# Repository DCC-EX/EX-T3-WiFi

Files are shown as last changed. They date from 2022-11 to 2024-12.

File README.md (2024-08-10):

<h1>EX-T3-WiFi <small>(T3 = Tactile Touch Throttle)</small></h1>

## WiFi throttle for DCC-EX Command Stations

#### The CS will need to be WiFi compatible and version 4.1.3+

#
### ⚠ Please note before deciding to buy parts this has been a solo project and may have unknown bugs and require some tinkering, please report any issues on GitHub ⚠

### 🛈 To upload the code you'll need a Chromium based web browser (Chrome, Opera, Edge) or Visual Studio Code and PlatformIO 🛈

#

## Parts
 - DFRobot FireBeetle 2 - DFR0654-F - https://www.dfrobot.com/product-2231.html (If you prefer a more permanent setup you could use the FireBeetle2 that doesn't have headers pre-soldered)
 - DFRobot Fermion: 3.5” 480x320 TFT LCD Capacitive Touchscreen - DFR0669 - https://www.dfrobot.com/product-2107.html
 - DFRobot Fermion: EC11 Rotary Encoder - SEN0235 - https://www.dfrobot.com/product-1611.html
 - DFRobot Fermion: LIS2DW12 Triple Axis Accelerometer - SEN0405 - https://www.dfrobot.com/product-2337.html **(This is optional but will allow the throttle to rotate the display with orientation)**
 - Miniature Slide Switch SPDT - I used one from here https://www.hobbytronics.co.uk/slide-switch?search=switch
 to fit the case it'll need to be the same dimensions *(19mm long, 5.6mm wide, 5mm high and mounting holes 15mm apart)*
 - 3000mah\2000mah LiPo battery - https://shop.pimoroni.com/products/lipo-battery-pack?variant=20429082247 **⚠ This battery has the terminals the correct way but before connecting any battery check the wires are the right way round on the plug ⚠**
 - All screws are self tapping cap heads;
	- M2x5mm - x6 (+2 if using accelerometer) (+2 if using 3000mah battery)
	- M2x8mm - x6 (+2 if using 2000mah battery)
	- M3x6mm - x2
	- M3x20mm - x4
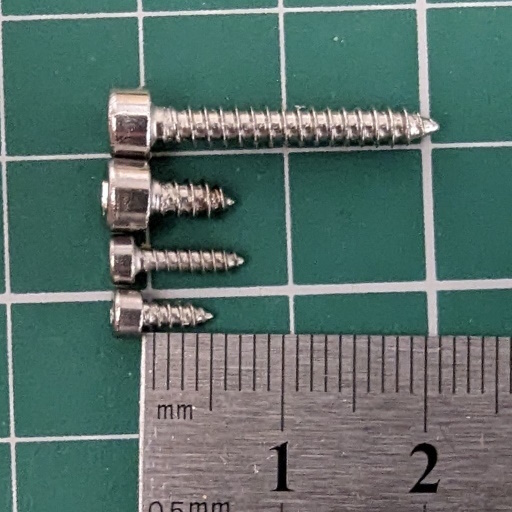
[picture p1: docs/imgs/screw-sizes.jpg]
	
 - Stranded and solid core wire depending on preference
 - If using headers then you'll need some right angle male, right angle female and standard female
 - Heatshrink for wires
 - MicroSD card (16GB is a good common size)

#
- [Assembly](/docs/assembly.md)
- [Web Browser Uploading](/docs/browser.md)
- [VSCode Uploading](/docs/code.md)
- [Throttle Setup](/docs/setup.md)
- [Managing Locos](/docs/locos.md)
- [Throttle Menu](/docs/menu.md)
- [Throttle Settings](/docs/settings.md)
- [Running Locos](/docs/running.md)
- [Decoder Programming](/docs/programming.md)

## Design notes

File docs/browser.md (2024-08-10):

# Web Browser Uploading

> ⚠ Web browser uploading only works with Chromium based web browsers such as Chrome, Opera & Edge ⚠

Download the lastest release from https://github.com/DCC-EX/EX-T3-WiFi/releases (`firmware.bin`) then go to https://espressif.github.io/esptool-js/

Plug in the throttle to your computer and click the `Connect` button (You'll be prompted to select the COM port the throttle is on).

If the throttle has been detected it should read **Connected to device**.

On the `Flash Address` field change the value to `0x0` then click the `Choose File` button and select the `firmware.bin` file you downloaded earlier.

You can now click the `Program` button to begin uploading.\
The upload progress will show below.\
Wait until it gets to 100% and finishes with the output of `Leaving...` before disconnecting the throttle.

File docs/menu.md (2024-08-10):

# Throttle Menu

## Loco
  * **By Address** - Display a keypad so a loco address can be selected.
  * **By Name** - Lists names of locos the throttle has configs for.
  * **By Group** - Lists the configured loco groups.
  * **Release** - Release the current loco.
  * **[Program](/docs/programming.md)** - Show the program track options.

## Accessories
 * **On** - Display a keypad so an accessory address can be selected and an **On** command sent.
 * **Off** - Display a keypad so an accessory address can be selected and an **Off** command sent.

## Power
 * **On/Off All** - Toggle power for **Main** and **Prog** tracks.
 * **On/Off Main** - Toggle power for the **Main** track.
 * **On/Off Prog** - Toggle power for the **Prog** track.
 * **Join Tracks** - Join the **Main** and **Prog** tracks.

## Settings
  * **T3 WiFi** - Starts the throttles local WiFi, Web Server and displays the throttle connection details.\
  *To manage the configs for locos you need to be on this screen.*
  * **Settings** - Manage the throttle settings.
  * **About** - Version details about the throttle and the CS if it's connected

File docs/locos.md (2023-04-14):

> Remember, to manage locos you'll need to start and connect to the web server on the throttle.\
Refer to [Throttle setup](/docs/setup.md).

# Managing Locos

Click the green **+** icon to add a new loco config or click the pencil icon on an existing loco to edit it.

<p align="center">
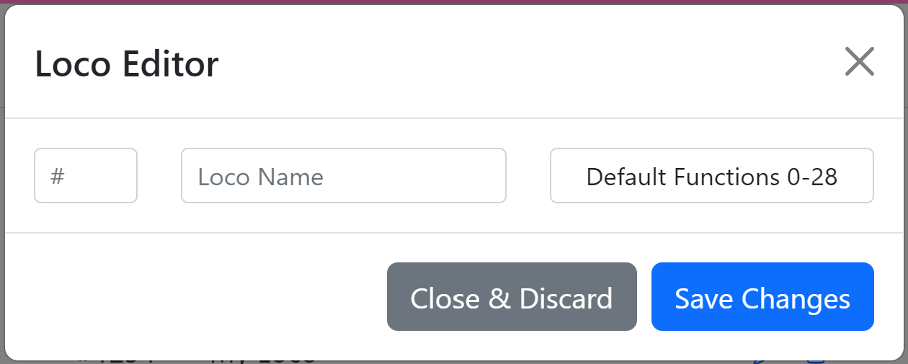
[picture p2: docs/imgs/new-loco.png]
  
</p>

A window will open where you can enter the details of the new loco.
* Enter the loco address in the field with the **#**.
* Enter a loco name in the **Loco Name** field, this is just for your reference so can be anything *(Max 20 characters)*.
* The last option is a dropdown, by default a loco will have buttons for functions 0-28 but you can create re-usable function sets or have a custom function set per loco.
<p align="center">
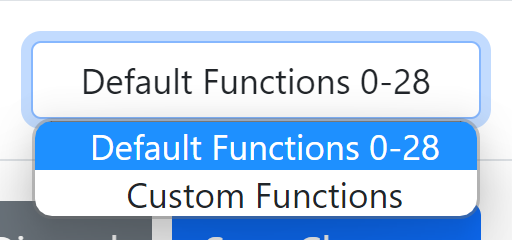
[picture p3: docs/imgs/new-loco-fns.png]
  
</p>

# Custom Functions

Each loco can have a custom function set.\
If you have more than 8 rows of buttons paging will be enabled and there will be 7 rows per page.\
Each row can have a max of 4 buttons.

<p align="center">
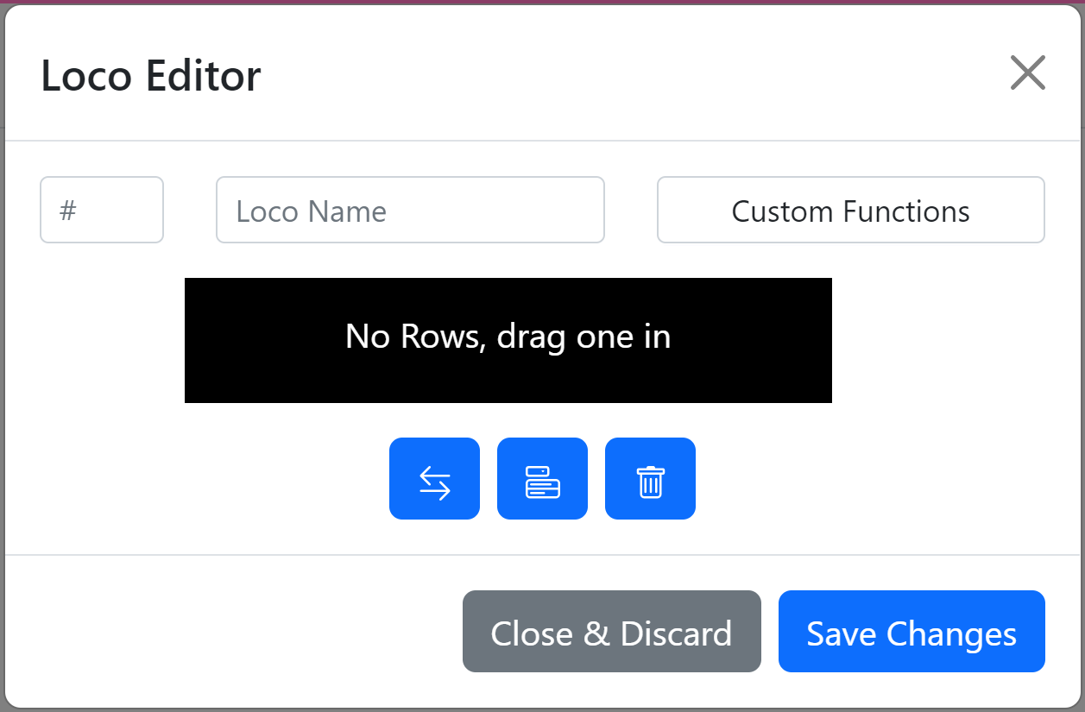
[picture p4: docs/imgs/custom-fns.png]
  
</p>

Start by dragging in a row, click and hold the button with the arrows then drag it into the black area.

<p align="center">
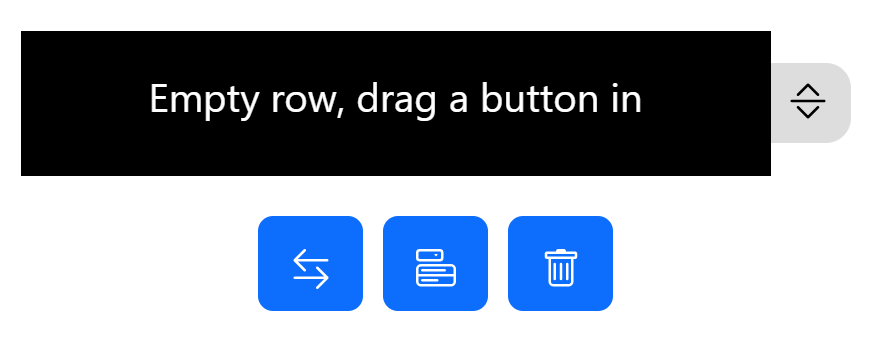
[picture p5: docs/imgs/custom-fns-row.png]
  
</p>

You can now drag in a button, click and hold the middle blue button and drag it on to the row.\
New buttons will use the next highest available fn #.

<p align="center">
  
</p>

Clicking the button will expand it so you can change the FN number and if it's a latching function or not.

<p align="center">
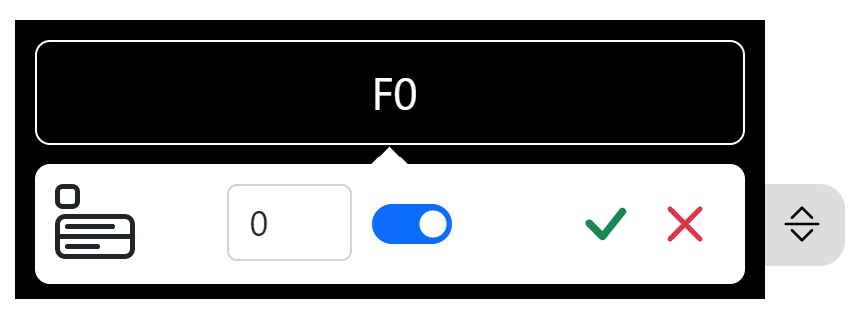
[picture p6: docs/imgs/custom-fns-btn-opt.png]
  
</p>

After making any changes remember to click the green tick icon so the changes are saved.\
If you've made changes you wan't to discard then click the red **X**.

For more advanced options click the icon to the left of the FN number.

From here you can set the button labels, colours and icons for **Idle** and **Pressed**.\
Clicking the icon circled in red will toggle between the **Idle** and **Pressed** states so you can preview.

> Click an icon to select it, click it again to deselect it.

<p align="center">
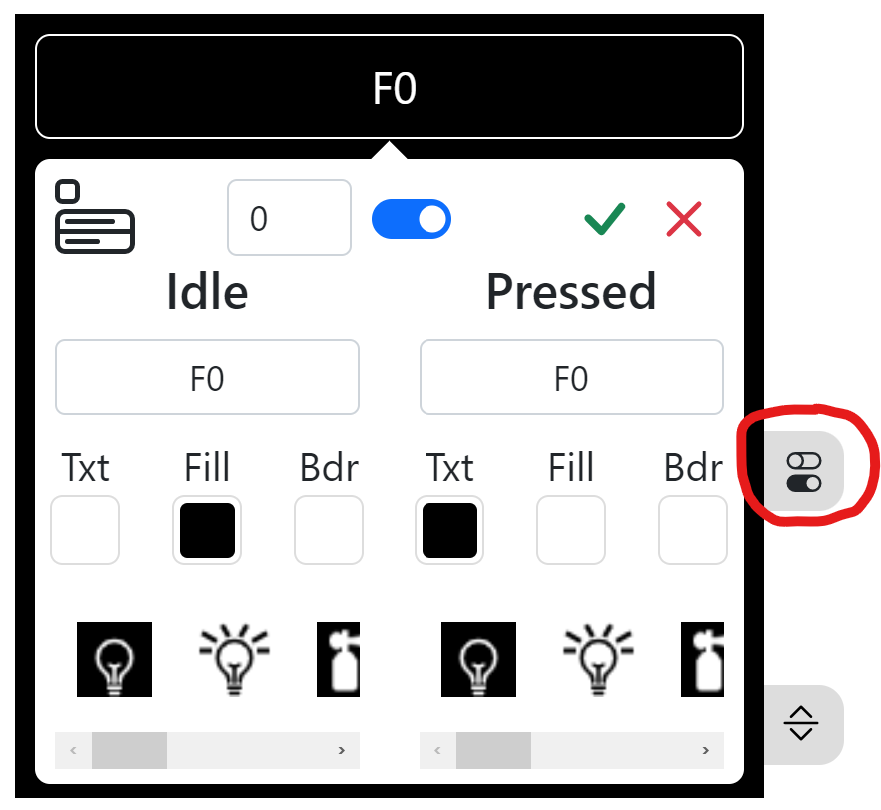
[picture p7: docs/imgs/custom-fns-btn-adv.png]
  
</p>

Rows can be dragged and reordered by clicking and holding the below icon that is at the end of each row.
<p align="center">
  
</p>
Buttons can be moved between rows by clicking and holding the dragging between rows.

> Remember a row can have a max of 4 buttons

# Function Sets

Reusable function sets can also be created.\
This is useful if you want to create a function set for a specific decoder that's used in multiple locos.

The function set name is for your reference.\
This will be the name that will appear in the dropdown when managing a loco as above.

Functions are created as per the instructions above.

<p align="center">
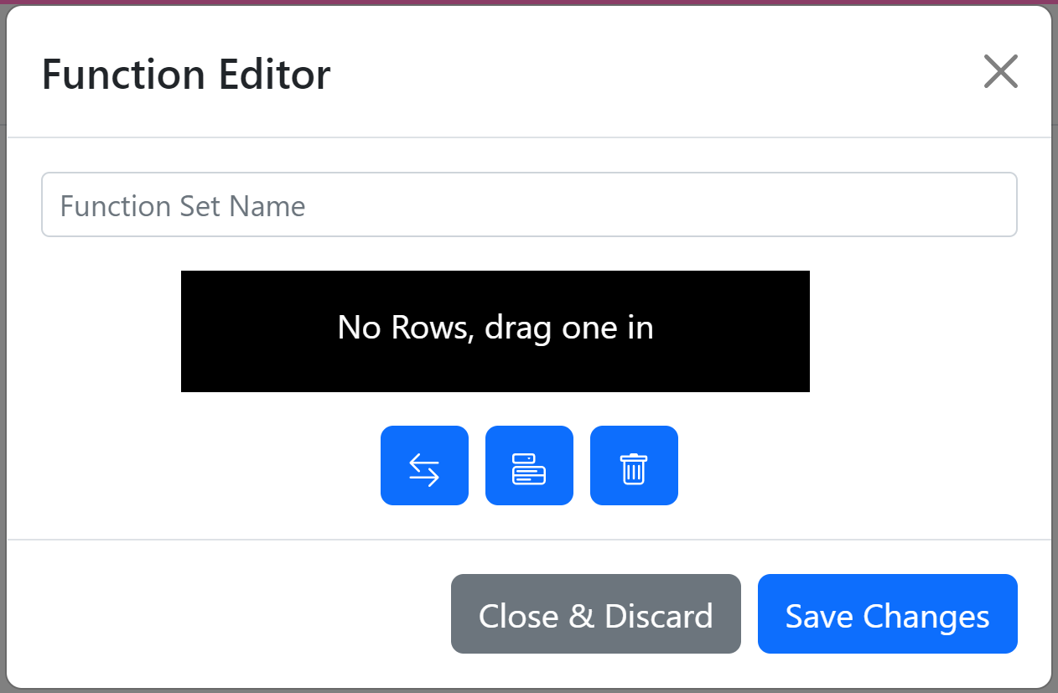
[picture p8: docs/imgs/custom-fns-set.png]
  
</p>

> There's also an upload icon (next to the +) so if a new decoder function set gets added to GitHub you can upload it without needing to take the SD card out.

# Groups

Here you can create loco groups that will show when the **By Group** button is pressed on the throttle menu.

Each group on the throttle will display as a button.\
Pressing a group button will then list the locos within it.\
You can then press a loco button to control that loco.

To add a new group click the large green **+** icon.\
This will add a new blank group.

<p align="center">
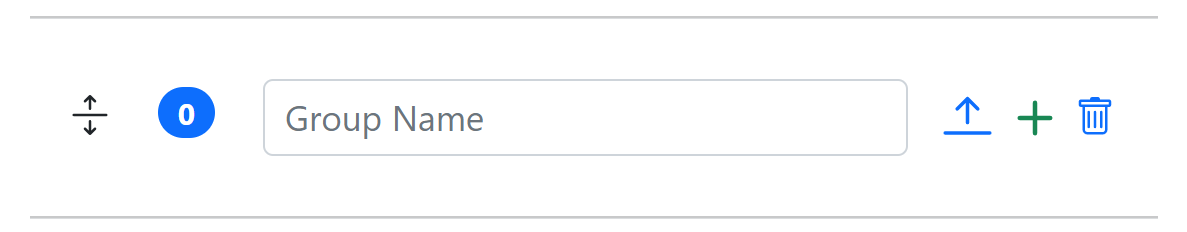
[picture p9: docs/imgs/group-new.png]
  
</p>

Enter a name in the `Group Name` field *(Max 20 characters)*.\
To add locos click the small green **+** icon on the group.\
This will open a new window where you can either enter loco addresses manually or select existing locos the throttle has a config for.

<p align="center">
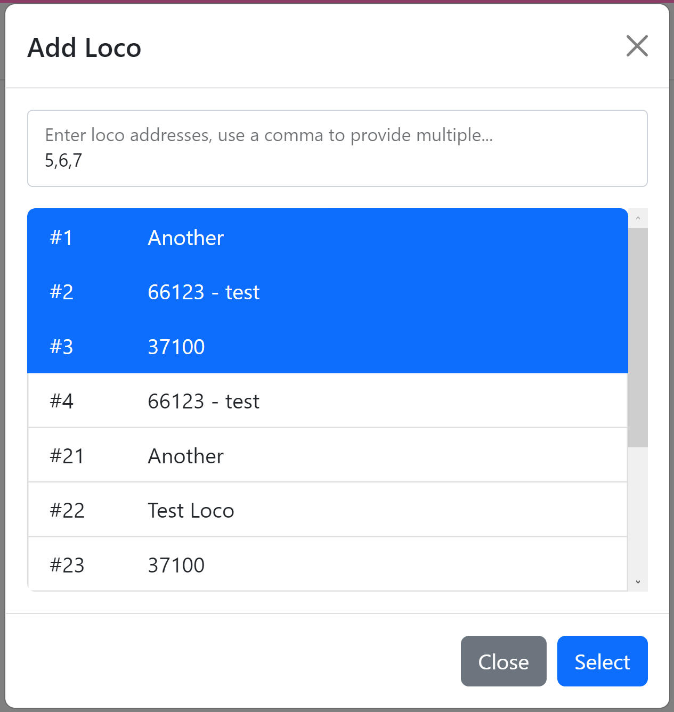
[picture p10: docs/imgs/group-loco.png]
  
</p>

Click the **Select** button to add the locos to the group.

<p align="center">
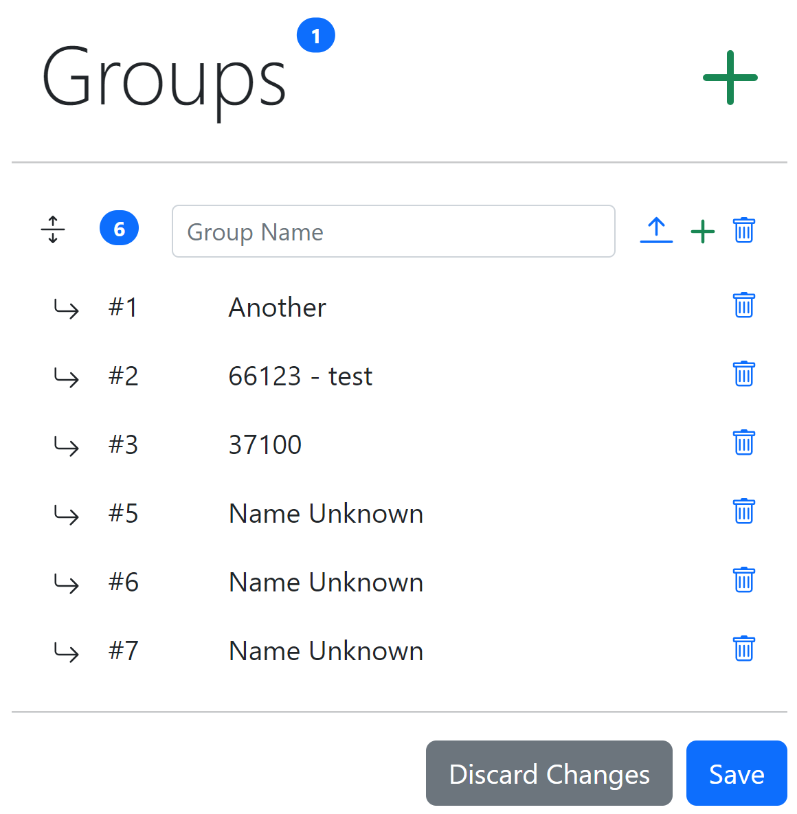
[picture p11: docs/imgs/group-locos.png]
  
</p>

Locos in the group will be listed below.\
If the throttle has a loco config it'll use the name otherwise it will show as **Name Unknown**.

Locos in the group will appear in the same order on the throttle.\
They can be reordered by click holding a dragging.\
Loco groups can also be reordered by dragging.

To save on display space a loco group is loaded as collapsed by default.\
You can expand/collapse a group to show the locos by clicking the arrow icons.

<p align="center">
  
  
</p>

# Icons

You can upload your own icons to use with the function buttons.

These need to be 24bit bitmaps with max dimensions of 30x30.

# Downloading/Uploading configs
Configs for locos, function sets and groups can be downloaded and uploaded.
An individual loco/function config can be downloaded by clicking the download icon to the left on the list.\
You can download all loco/function configs by clicking the download icon at the top of the list.\
Upload loco/function configs by clicking the upload icon at the top of the list, you can select single or multiple files to upload.\
(**Warning, Uploaded configs with the same addresses/names will overwrite any existing**).

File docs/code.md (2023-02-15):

# Uploading the Code

Start by uploading the embedded file system.\
On the PlatformIO tasks list click the `Upload Filesystem Image` task.
<p align="center">
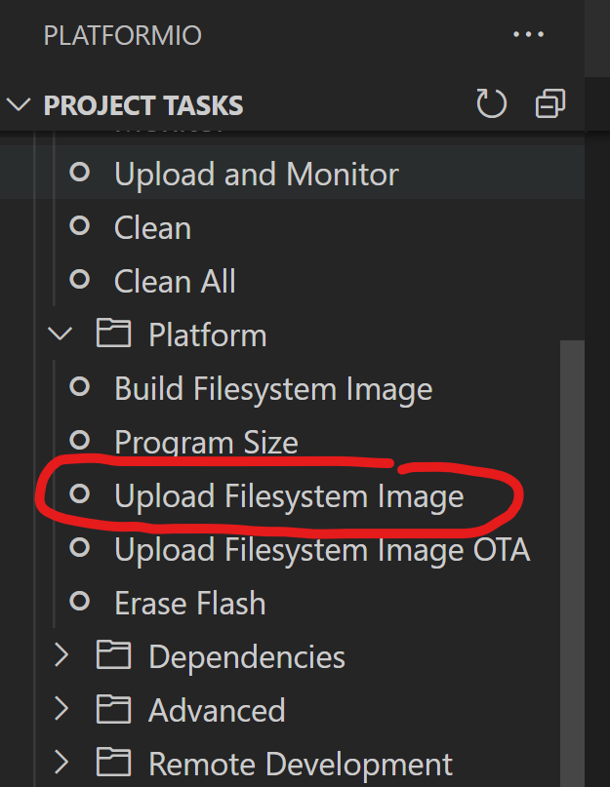
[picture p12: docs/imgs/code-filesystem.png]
  
</p>

## Uploading the code

Either of the options below will upload the code to the FireBeetle but **Upload and Monitor** can help with debugging any issues.
<p align="center">
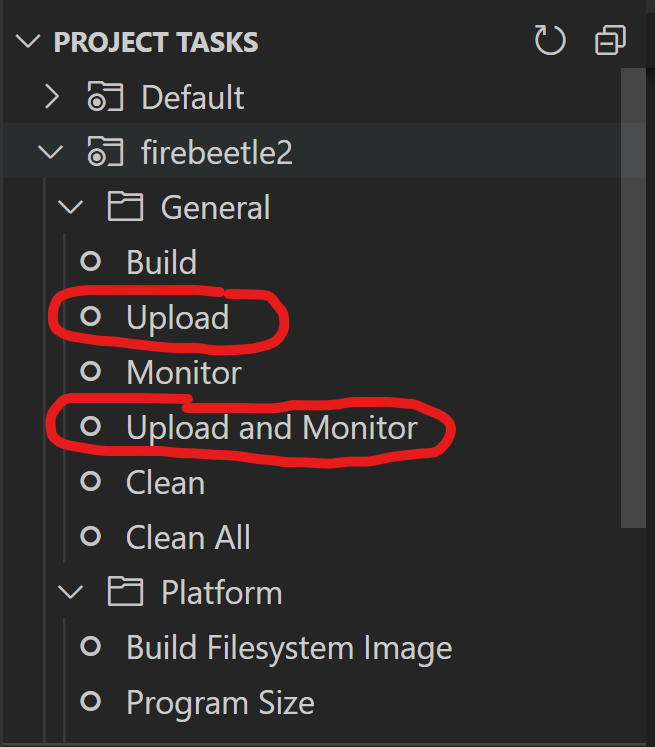
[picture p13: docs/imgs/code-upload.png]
  
</p>

# Command Station

If you want some extra functionality you'll need to update your **Command Station**.\
This step is optional and the throttle will still function without it but it won't be able to query the **CS** for the current power states.

Included is a file named `myFilter.cpp`, this needs to be copied to the folder that contains the **Command Station** code and uploaded to your **Command Station**.

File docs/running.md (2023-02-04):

# Running Locos

There's 3 ways to select a loco to control.

 * **By Address** - This will show a keypad where a loco address can be entered, press *Enter* to aquire and control the loco.
  * **By Name** - This will list all the locos the throttle has configs for, press a loco name to select.
  * **By Group** - This will list the groups *([as configured](locos.md#groups))*. Pressing a group button will list all the locos within that group, press a loco name to select.

---

The dial on the throttle is used to control the speed and direction.
* Turn clockwise to increase speed
* Turn counterclockwise to decrease speed
* Press once to change the loco direction

> Press and hold the dial to emergency stop all locos, the default is a 2 second hold but this can be changed in the throttle settings

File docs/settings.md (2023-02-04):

# Throttle Settings

These are under the **Settings** button from the menu.\
Settings are across multiple pages, you can scroll through them by using the paging buttons at the bottom.

## Loco UI

**Speed Step** - Can be 1, 2 or 4. This is the step value used to control loco speeds. *This is for the throttle only and not related to DCC speed steps*.

Some basic swipe gestures are supported on the throttle, Up, Down, Left & Right.\
Each gesture can trigger an action.

> Gestures only work while on the loco display

* **Keypad** - Show the keypad to select loco address.
* **Name** - Show the list of locos the throttle has configs for.
* **Group** - Show the loco groups the throttle has configs for.
* **Next** - If multiple locos have been selected then control the next.
* **Prev** - If multiple locos have been selected then control the previous.
* **Release** - Release the current loco.

> Locos are remembered in the order they were selected.\
So **Next** and **Prev** will follow this order.

**After swipe release**\
The action to perform if a swipe action is set to **release**.\
If this is set to **Next** or **Prev** and there's no locos the throttle will go back to the menu.

## Screen Rotation

* **Standard** - Screen above with rotary encoder below
* **Inverted** - Screen at below with rotary encoder above.
* **Accelerometer** - *Only if used*, display will rotate with pyhsical orientation.

## Pin Protect

This is just some basic security if you're concerned about guests being able to make changes to your settings.\
A 9 digit max pin can be set which will be required to access the `T3 WiFi` and `Settings` displays.

If the button is idle and reads `Not Set` no pin is set, you can set one by pressing the button which will show a keypad.\
Enter a pin and press `Enter` to set it or `Cancel` to go back to the settings.

To remove a pin press the button when it reads `Pin Set` to show the keypad then just press `Enter`. This will remove the pin and the button will change to `Not Set`.

> If you forget your pin it's stored in the `settings.json` file on the MicroSD card so can be read or reset.

## Emergency Stop Trigger Hold Duration

The milisecond count the encoder is pressed for to trigger an emergency stop of all locos (can be between 1000 - 5000 miliseconds).

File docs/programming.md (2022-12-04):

# Decoder Programming

Programming options are under the **Program** menu button and only work on the programming track.

- **Read Address** - Read the decoder address.
  1. If successful the decoder address will be displayed.
- **Write Address** - Write a new address to the decoder.
  1. Enter an address on the keypad (`1-10293`), press enter.
  2. A confirmation message will show, press **Yes** to write the address or **Cancel** to go back to the menu.
  2. If **Yes** was pressed then a success or fail result will show.
- **Read Byte** - Read a decoder CV value.
  1. Enter a CV number on the keypad (`1-1024`), press enter.
  2. If successful the byte value will be displayed.
- **Write Byte** - Write a CV value to the decoder.
  1. Enter a CV number on the keypad (`1-1024`), press enter.
  2. Enter a CV value on the keypad (`0-255`), press enter.
  3. A confirmation message will show, press **Yes** to write the CV value or **Cancel** to go back to the menu.
  4. If **Yes** was pressed then a success or fail result will show.
- **Read Bit** - Read a decoder CV value bit.
  1. Enter a CV number on the keypad (`1-1024`), press enter.
  2. Enter a bit number on the keypad (`0-7`), press enter.
  3. If successful the bit value will be displayed.
- **Write Bit** - Write a CV bit value.
  1. Enter a CV number on the keypad (`1-1024`), press enter.
  2. Enter a bit number on the keypad (`0-7`), press enter.
  3. Enter a bit value (`0-1`), press enter.
  4. A confirmation message will show, press **Yes** to write the CV bit value or **Cancel** to go back to the menu.
  5. If **Yes** was pressed then a success or fail result will show.

When on a keypad press **Cancel** to go back to the programming options menu.

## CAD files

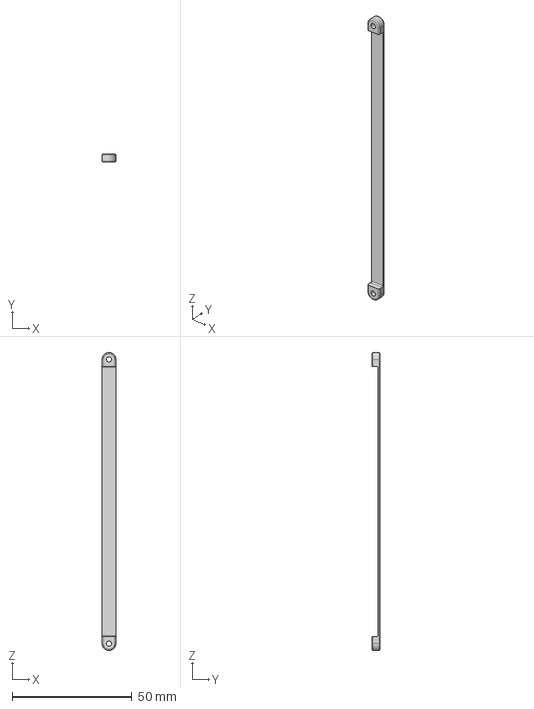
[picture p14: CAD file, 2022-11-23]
3d/Battery Strap - 2000mah.step
5.75 x 3.50 x 124.5 mm

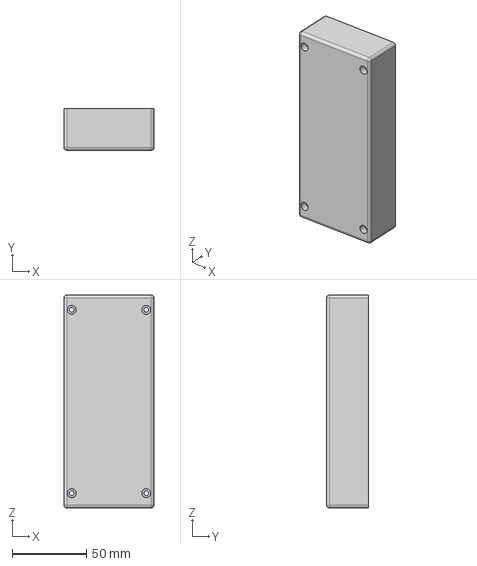
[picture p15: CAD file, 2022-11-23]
3d/Body.step
60.6 x 28.0 x 143.0 mm

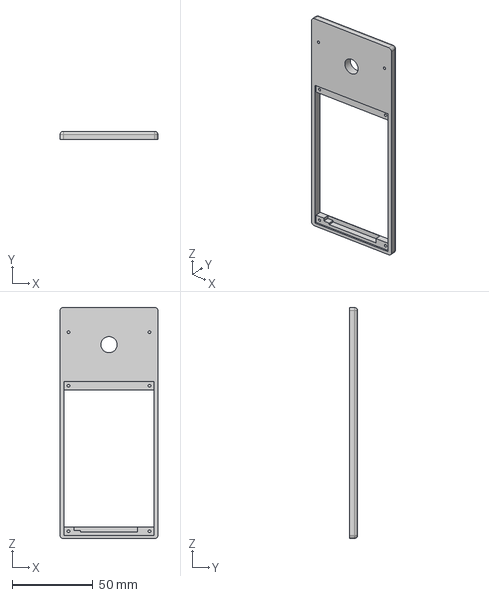
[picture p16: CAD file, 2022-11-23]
3d/Top.step
60.6 x 5.25 x 143.0 mm

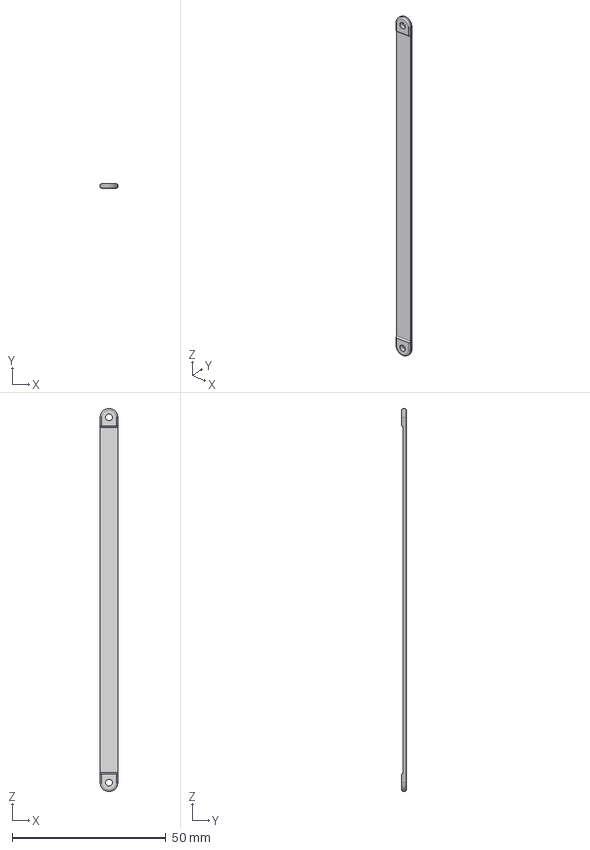
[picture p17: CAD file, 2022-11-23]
3d/Battery Strap - 3000mah.step
5.75 x 1.50 x 124.5 mm

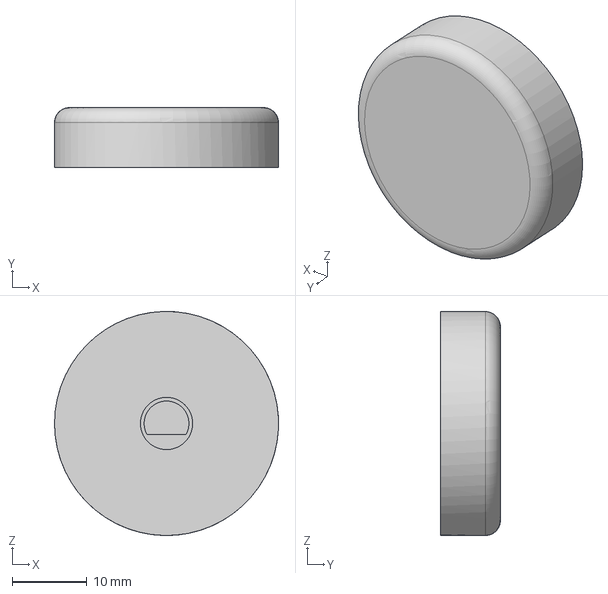
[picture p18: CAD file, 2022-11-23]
3d/Dial.step
30.0 x 8.00 x 30.0 mm

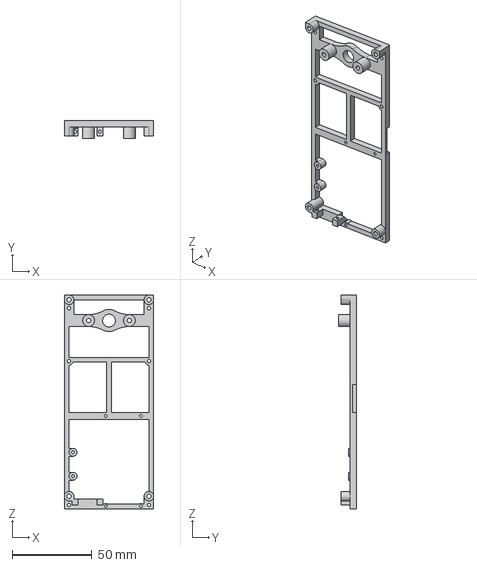
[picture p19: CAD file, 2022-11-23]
3d/Frame.step
56.0 x 11.3 x 134.0 mm

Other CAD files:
3d/Battery Strap - 2000mah.stl
3d/Battery Strap - 3000mah.stl
3d/Body.stl
3d/Dial.stl
3d/Frame.stl
3d/Top.stl

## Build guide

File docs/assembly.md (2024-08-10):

# Assembly

### ⚠ Before connecting the battery to the FireBeetle remember to check the wire polarity as not all batteries are the same ⚠

## Before starting assembly

This step is easier to do now while access is still easy.\
The MicroSD card needs to be inserted into the display.\
_The MicroSD card needs to be FAT32 formatted but the throttle is able to format the card if it can't be mounted.\
The format option is provided when the throttle is powered on and unable to mount the card._

## Case
The case is made of 5 3D printed parts which are needed for assembly.
- **Body.stl** - The main case body
- **Frame.stl** - The frame the FireBeetle2, rotary encoder, power switch and optional accelerometer mount to
- **Top.stl** - The case top and display & frame mount
- **Dial.stl** - Dial for the rotary encoder
- **Battery Strap - 3000mah.stl** or **Battery Strap - 2000mah.stl** depending on what size battery

## Parts
<p align="center">
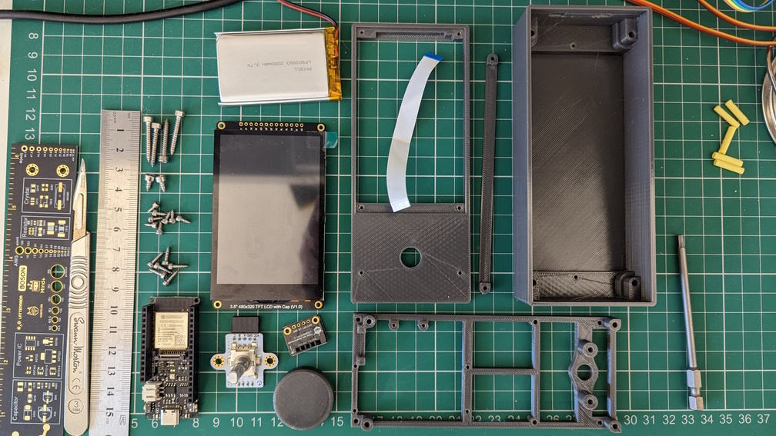
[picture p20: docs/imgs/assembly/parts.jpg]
  
</p>

## Pre-assembly soldering
_Depending on how you prefer to attach the wires_

I like to use header pins so used a female 90 degree header on the rotary encoder. This needs to be soldered like below.\
You can then use a male header to solder the wires to (covered later, makes it so parts can be replaced if needed).
<p align="center">
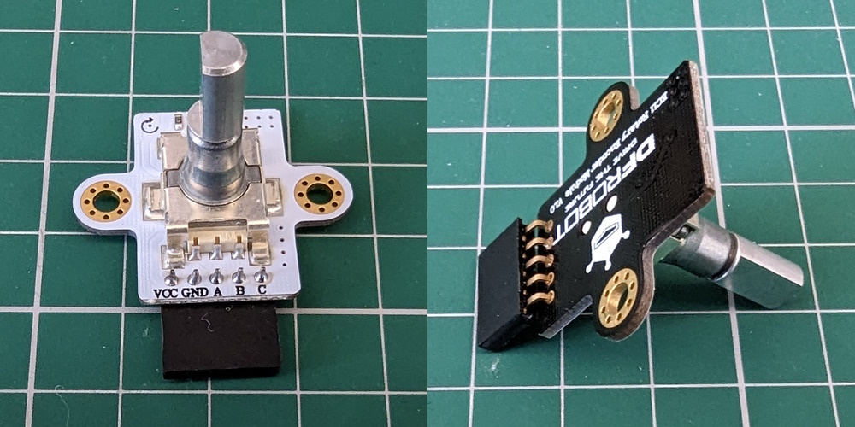
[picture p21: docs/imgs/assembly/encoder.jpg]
  
</p>
If using an accelerometer, the header needs to be soldered as below so the pins will line up later.
<p align="center">
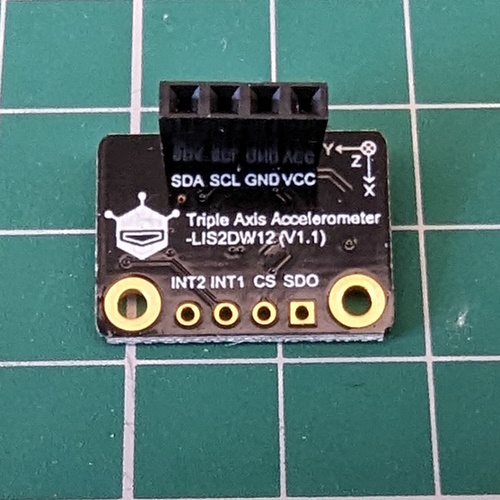
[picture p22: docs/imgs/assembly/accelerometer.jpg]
  
</p>

## Assembly
1.  ### Top and display 
    > ⚠ The top is designed to fit the display snugly so it's best to gently try and fit first and see if some light filing\trimming is required

    Attach the ribbon cable to the display and insert the display in to the top part of the case. The ribbon should be on the right and the MicroSD card on the left.
    <p align="center">
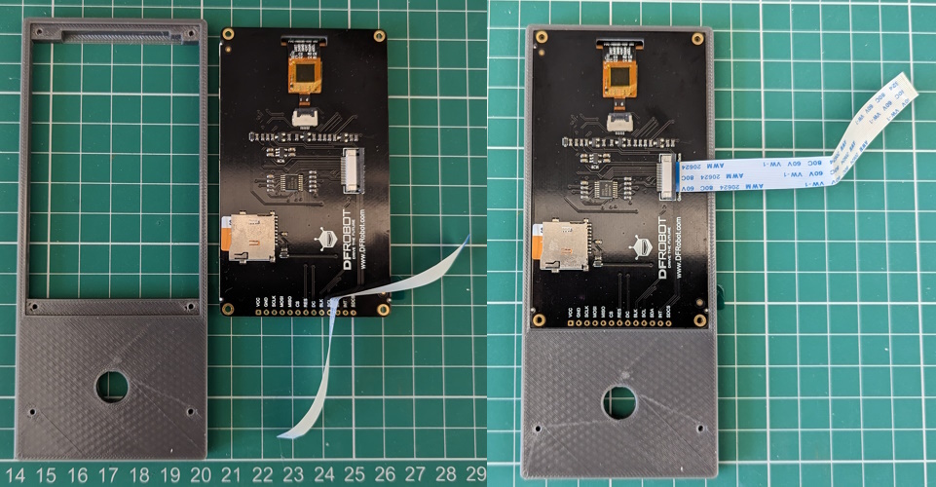
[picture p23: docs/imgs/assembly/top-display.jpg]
      
    </p>

2. ### Frame and FireBeetle2
    Attach the FireBeetle2 to the **Frame** using 4 M2x5 mm screws.
    <p align="center">
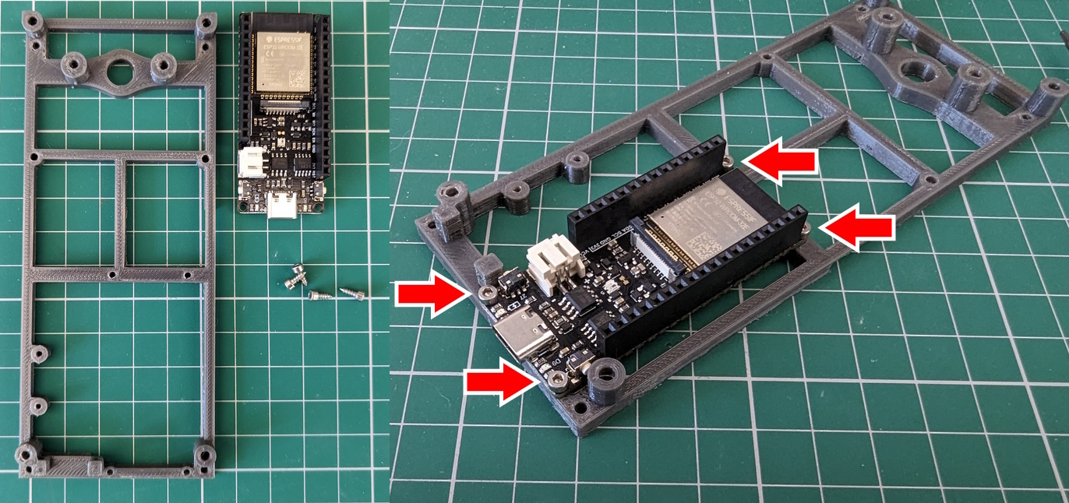
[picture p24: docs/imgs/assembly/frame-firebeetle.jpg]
      
    </p>

3. ### Frame and switch
    Attach the slide switch using 2 M2x5mm screws.
    <p align="center">
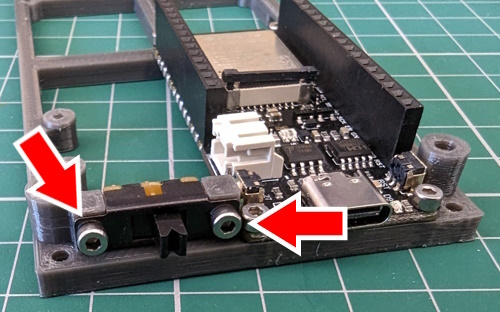
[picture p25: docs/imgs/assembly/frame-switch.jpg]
      
    </p>

4. ### Frame and accelerometer **_optional_**
    Attach the accelerometer using 2 M2x5mm screws.
    <p align="center">
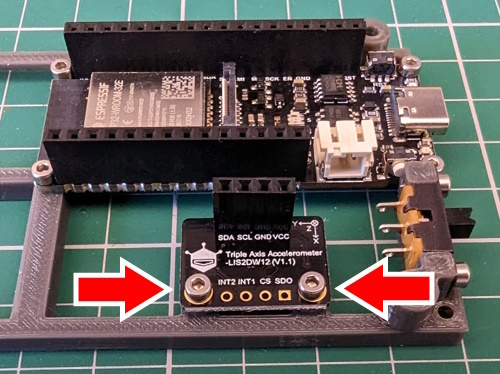
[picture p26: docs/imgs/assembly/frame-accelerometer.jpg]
      
    </p>

5. ### Join parts
    Attach the frame to the top using 6 M2x8mm screws, remember to pass the display ribbon cable through.
    <p align="center">
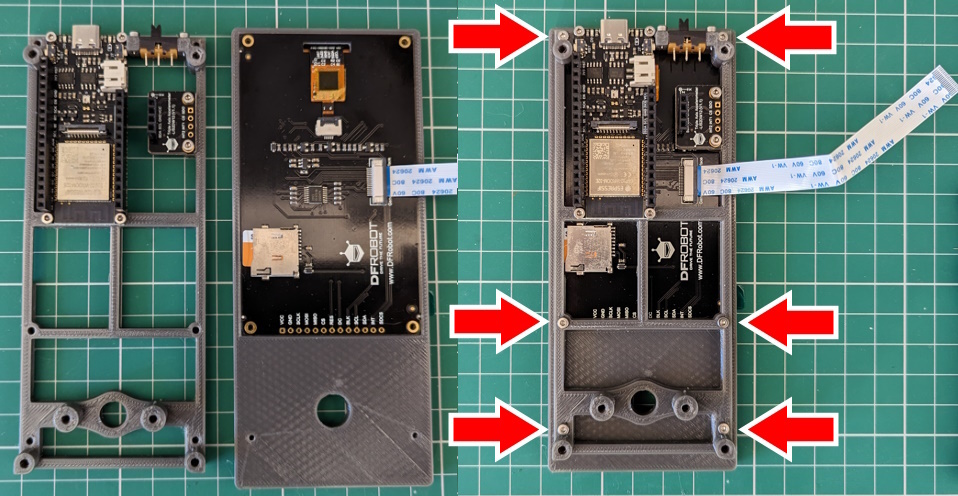
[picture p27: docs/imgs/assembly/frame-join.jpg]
      
    </p>

6. ### Ribbon cable
    After the frame is attached you can now connect the ribbon cable to the FireBeetle.
    <p align="center">
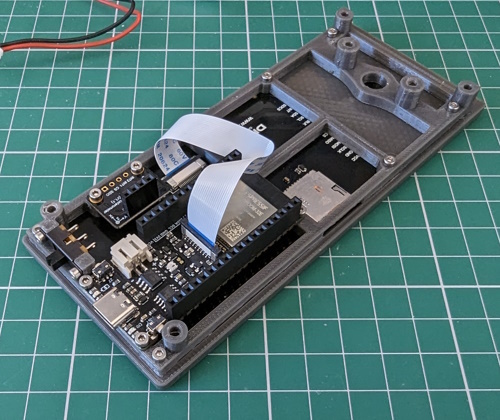
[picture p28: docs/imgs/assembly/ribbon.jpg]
      
    </p>

7. ### Rotary encoder
    Attach the rotary encoder to the frame using 2 M3x6mm screws
    <p align="center">
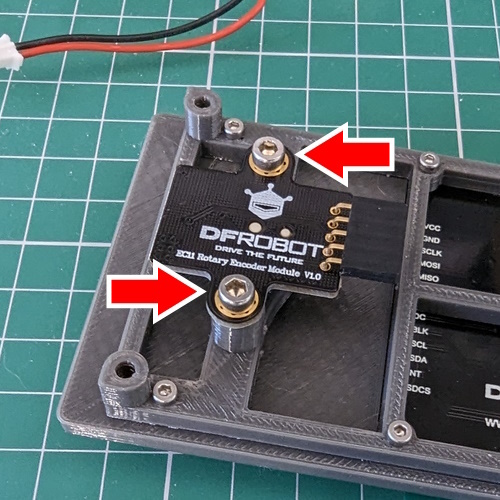
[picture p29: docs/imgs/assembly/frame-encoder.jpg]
      
    </p>

## Wiring

I soldered wires to 90 degree header pins with a bit of heatshrink.

> TIP: To help with soldering I cut off small pieces of brass tube (2mm OD, 0.25mm wall) to keep the wire steady. The brass tube can be cut by using a craft knife and applying pressure while rolling the tube back and forth.

<p align="center">
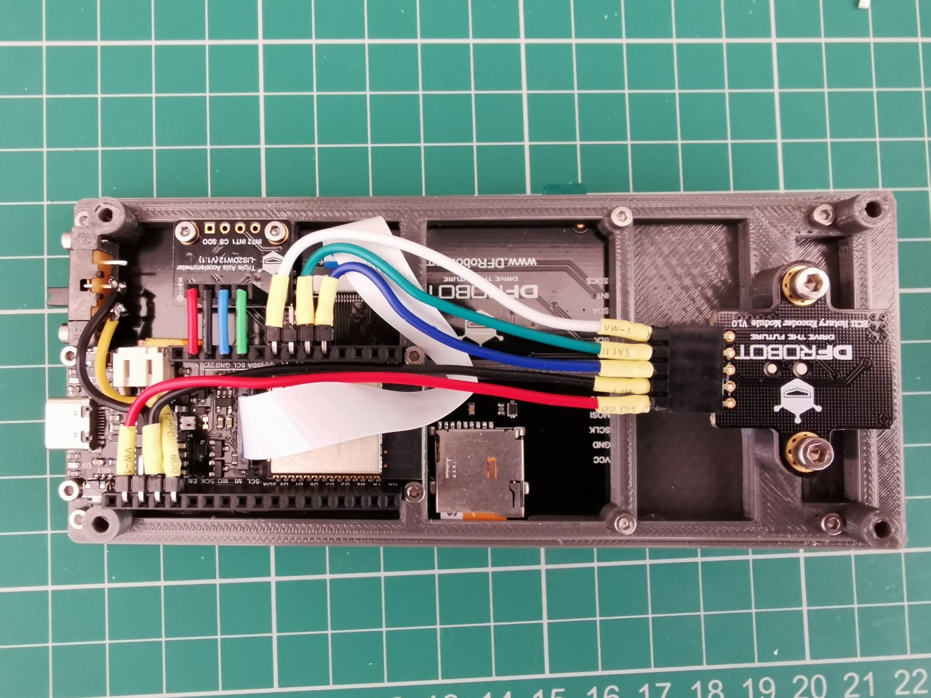
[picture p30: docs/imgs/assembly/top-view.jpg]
  
</p>

> If using the accelerometer you'll need to share a GND pin.\
The picture above shows how I did it.

 ### Encoder
 - Encoder C = FireBeetle A3
 - Encoder B = FireBeetle A1
 - Encoder A = FireBeetle A0
 - Encoder VCC = FireBeetle 3v3
 - Encoder GND = FireBeetle GND
 ### FireBeetle2
 - FireBeetle GND = Switch
 - FireBeetle EN = Switch
 > One wire needs to go to the middle pin of the switch while the other can go to either side. It depends if you have a preference for which position is on/off.
 ### Accelerometer (optional)
 The I2C headers are directly opposite each other so if you've soldered on a female header the easiest option here is some solid core wire.
 <p align="center">
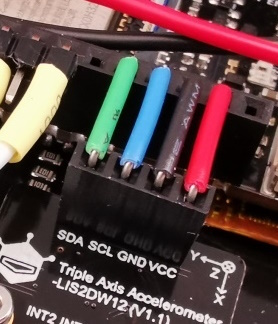
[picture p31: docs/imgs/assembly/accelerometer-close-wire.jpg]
  
</p>

## Securing battery

I used some electrical tape to secure the battery to the strap.\
This can then be attached to the body using M2 screws.
* 2000mah battery - 2 M2x8mm screws
* 3000mah battery - 2 M2x5mm screws
<p align="center">
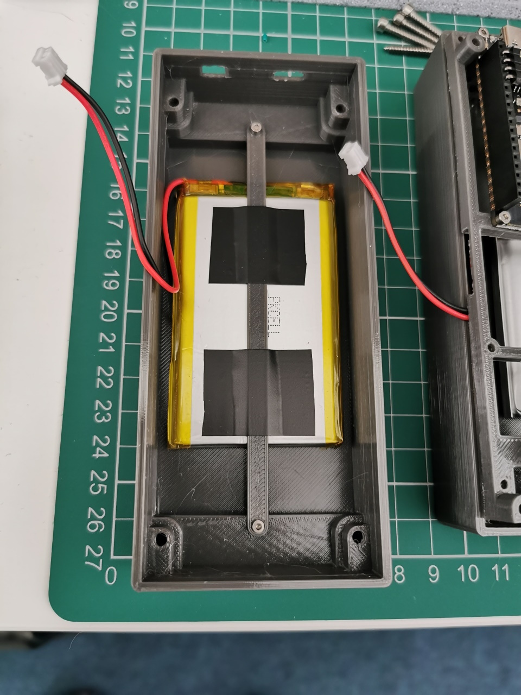
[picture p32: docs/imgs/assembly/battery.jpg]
  
</p>

## Final assembly

### ⚠ Before connecting the battery to the FireBeetle remember to check the wire polarity as not all batteries are the same ⚠

Connect the battery to the FireBeetle and insert the top section into the body.\
To allow clearance for the USB and power switch the top needs to be placed slightly back and slid forward.

The top can now be secured with 4 M3x20mm screws from the base.

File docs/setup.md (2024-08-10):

# Throttle Setup

> To manage locos, groups, icons & CS settings you'll need to be on the **T3 WiFi** display so the throttle website is accessible.

---

To connect the throttle to the CS you'll need to enter the WiFi settings, this is done from the **T3 WiFi** button on the main menu.

When on the **T3 WiFi** display you can touch any of the **CS Settings** labels to show a keyboard/keypad where you can enter the settings directly.

You can also connect to the throttles own WiFi and website (**AP Settings**) where you can enter the **CS Settings**.

## WiFi Settings
* SSID - The SSID of the WiFi network the CS is on *(Touch to show a keyboard)*.
* Password - The WiFi network password, if set *(Touch to show a keyboard)*.
* IP: The IP given to the throttle by the WiFi network.

## CS Settings
* Server - The CS server address. This can be a hostname or IP *(Touch to show a keyboard)*.
* Port - The CS port *(Touch to show a keypad)*.

## Throttle AP Settings
* SSID - This is the SSID of the throttle WiFi.
* Password - This is the password for the throttle WiFi.
* http:// - This is the website address for throttle management.

For convenience there's a QR code which can be scanned by a smartphone to connect to the throttle's WiFi.\
The QR code can be swipped left/right to provide a different QR code which will open the throttles built in web page.

> If you don't have smartphone you'll need access to a computer with WiFi so you can connect.

---

When the throttle is connected to your local WiFi or you're connected to the throttles own WiFi you can load the management website. 

Open a web brower and type the throttle address.

If you still need to enter the CS settings go to the **Settings** tab.\
Depending on how you setup your **Command Station** you'll need to enter the **SSID** and **password** of your local WiFi or the **CS** WiFi.

* **If your CS is connected to your local WiFi**\
The **server** and **port** are `dccex` and `2560` by default, you'll only need to change these if you changed them on your Command Station.
* **If your CS is in AP mode**\
The server will normally be this IP `192.168.4.1` and the port will still be `2560` unless you specified a different one.

Click save to remember the settings, the throttle will now try to connect to the CS.\
If connection is successful the icons will update

| | | | |
|---|---|---|---|
| <p align="center"><br />WiFi not connected</p> | <p align="center"><br />WiFi connected</p> | <p align="center"><br />CS not connected</p> | <p align="center"><br />CS connected</p> |

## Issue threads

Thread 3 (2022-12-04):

Sta mode IP address for throttle

jregholdsworth, 2022-12-04:
In setting up for sta mode IE using my home network the use of DNS didn't work so dccex couldn't be found.

So it changed to sta mode .however what is it's on home network IP address ..I couldn't find it using advanced  op scanner?..

I edited the SD card to insert the real IP address of the C's and that worked.

However to manage locos I need to access the throttles web page...without it appearing on the scan I'm stuck.

Any advice?

jregholdsworth, 2022-12-04:
Sorry advanced ipscanner and not C's CS

alex-code, 2022-12-04:
Were you on the `CS Settings and WiFi display` (The one with the QR codes)? The web server on the throttle is only active on this display.

jregholdsworth, 2022-12-04:
Yep I thought the throttle web server would move to my home network when I had the CS and the throttle connected to it..which would be very convenient.

Also having difficulty saving stuff to the SD card..eg loco names. Looked on the serial port and the output said that access to the SD was denied when creating the locos directory on the sd

Also I have to enter the password twice when accessing the ap for the throttle etc page using my windows laptop

alex-code, 2022-12-04:
The throttle server should be accessible when connected to your WiFi. Did you include `http://`?
When the throttle is connected and you're on the WiFi display are you able to ping it?

Ok, didn't notice git ignores empty directories so wasn't created.
There should be `locos` and `fns` directories on the SD card too.

Not sure about the password issue. It's just a WiFi AP so if you've entered the settings Windows should just connect.

jregholdsworth, 2022-12-04:
Even though the t3-ex-wifi connects as an sta to my home
network..192.168.0.xxx and can control my dccex C's which is also an sta on
my home network..the throttle web server remains at 192.168.4.1

Can't save to the SD card reliably is another problem..

If the SD card loco structure is the same as your tethered throttle I can
create a simple config by hand on the sd and give that a try.

I am really impressed despite these teething issues which in part are due
to my own dull nature

Regards JH

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

alex-code, 2022-12-04:
I'm working on a fix for the SD missing directory issue, just didn't notice git omits empty directories which means some that are required will be missing if you copy the `sd` directory.

alex-code, 2022-12-04:
I've updated the code with a fix for the missing directories.
The throttle will now create them if needed.

Have you been able to access the throttle's website?
If in STA mode the throttle's IP will come from your router, it doesn't set its own.

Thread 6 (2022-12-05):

compilation problem in new release

jregholdsworth, 2022-12-05:
Fails during compilation with the following output:

lots of good stuff then

Compiling .pio\build\firebeetle2\FrameworkArduino\stdlib_noniso.c.o
Compiling .pio\build\firebeetle2\FrameworkArduino\wiring_pulse.c.o
Compiling .pio\build\firebeetle2\FrameworkArduino\wiring_shift.c.o
In file included from lib/UI/Img/Img.cpp:2:
lib/UI/Img/BMP.h:9:31: error: expected class-name before '{' token
 class BMP : public ImgHandler {
                               ^
lib/UI/Img/Img.cpp: In static member function 'static Img* Img::load(fs::File)':
lib/UI/Img/Img.cpp:9:25: error: cannot convert 'BMP*' to 'Img*' in return
       return new BMP(img);
                         ^
*** [.pio\build\firebeetle2\lib258\UI\Img\Img.cpp.o] Error 1

alex-code, 2022-12-05:
`Img.h` & `Img.cpp` were renamed.

How did you update?

jregholdsworth, 2022-12-05:
I down loaded the new code files from git hub to the old location..reloaded
the project files and then tried a test compile..I'll create a completely
new folder and try again

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

jregholdsworth, 2022-12-05:
Apologies I cleaned and made a new folder and it works...the throttle has
an ip address of 192.168.0.202...god only knows why the router chose this
but it works..DHCP works in mysterious ways?

Thanks again..

Ps I note that although the throttle web page is inactive when the T3
button isn't pressed I can still ping it's address and get a response..

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

alex-code, 2022-12-05:
Glad you got it working.
A device can respond to a ping without having an active server.

Closed 2022-12-05.

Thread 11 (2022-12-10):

error: expected class-name before '{' token  class BMP : public ImgHandler {

daveclifford, 2022-12-10:
**Describe the bug**
Running Visual Studio Code app in Linux
Note BMP.cpp and BMP.h are dated 2022/12/08; Img.cpp and Img.h are dated 2022/11/29

snippet of the code complie log  pasted below:
"In file included from lib/UI/Img/Img.cpp:2:
lib/UI/Img/BMP.h:9:31: error: expected class-name before '{' token
 class BMP : public ImgHandler {
                               ^
lib/UI/Img/Img.cpp: In static member function 'static Img* Img::load(fs::File)':
lib/UI/Img/Img.cpp:9:25: error: cannot convert 'BMP*' to 'Img*' in return
       return new BMP(img);
                         ^
*** [.pio/build/firebeetle2/lib843/UI/Img/Img.cpp.o] Error 1"

**To Reproduce**
Steps to reproduce the behavior:
1. re-run build job

**To Reproduce**
Steps to reproduce the behavior:
1. Go to '...'
2. Click on '....'

**Expected behavior**
Compiles to end w/o error code

**Screenshots or debug output**
If applicable, add screenshots or debug output to help explain your problem.
*Debug output can be obtained from the serial monitor*

**Additional info**
 Executing task in folder EX-T3-WiFi-master: platformio run --environment firebeetle2
Processing firebeetle2 (platform: espressif32@^5.2.0; board: firebeetle2; framework: arduino)

alex-code, 2022-12-10:
`Img.h` and `Img.cpp` were renamed.
You'll need to delete those or start with a new directory with downloading/cloning.

daveclifford, 2022-12-14:
Thanks - did "You'll need to delete those or start with a new directory with downloading/cloning" and fixed issue.

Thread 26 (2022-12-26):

Pin code protection for WiFi and settings

alex-code, 2022-12-26:
Option to set a pin code that will be required to change WiFi or throttle settings.

alex-code, 2023-01-15:
Closed by #35

Closed 2023-01-15.

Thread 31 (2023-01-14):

README.md - RE: "This battery has the terminals the correct way but before connecting any battery check the wires are the right way round on the plug"

daveclifford, 2023-01-14:
[For your review - This may clarify what the user should do to ensure the positive voltage is in the correct position.]

The JST-PHR-2P Li-Po battery connector has a red-colored lead representing the positive polarity and when plugged into the socket on the side of the FireBeetle2, should face the back (toward the ESP32 chip) There is a Plus (+) indicator on the underside of the board indiccating the battery positive connection.

The user may use a Volt-Ohm-Meter (VOM) to measure the voltage (if charged) to ensure the positive voltage is at the red wire and in the right position (when looking at the connector head-on).

alex-code, 2023-01-14:
Good idea, will look at adding some extra pictures of the connectors and more instructions to help check the battery polarity is correct.

daveclifford, 2023-03-16:
In order to keep this open,

I will offer you some additional information on the battery and system power draw.

I purchased a USB Tester when I was having connectivity issues and wanted to eliminate poer/interface issues.

The unit is a DRok USB tester and has a USB dongle with USB A and USBC plugs as input to the tester.
There is a voltage line (in red) and a power line (in blue).

The FireBeetle2  draws:

5.07 Volts and 0.15-0.16 Amps  (150-160ma)

The chip is slightly warm to my index finger.

Dave

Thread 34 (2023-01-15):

Ideas : Documentation Improvements

Alan-Lomax, 2023-01-15:
Not a problem but an observation:

- In reviewing the assembly.md it is clear that a lot is left unsaid. Scrolling down to the first picture I see an accelerometer screw down and some details about wiring it. It occurs to me that is not an assembly step but a wiring detail.
- I think this document should start with 'a box of parts' and lead step by step putting it all together.
- The details of how to tackle specific items in the process is good and must not be lost .. but it is not part of the main 'assembly flow'
- Other examples observed further down - for example - firebeetle is attached to frame - ok but in the photo the frame is already attached to something - when did that happen?  Are other parts attached to the frame first?

NEXT
- Usage Cases - I saw several places where the accelerometer is described as optional. I could not find why I might want to use it.
- A block diagram of the subassemblies and how they integrate could provide some context. Wiring the switch and what it is connected to etc.

In my case I have ordered my parts and started 3D printing the case.
While awaiting delivery I have been reading and re-reading what I can.
I like what I have seen but some polish here could really raise the profile

alex-code, 2023-01-15:
There's definitely room for improvement.
The pictures are a bit out of step as I built it first before going back to get some pictures so some parts that would be done later already exist.

When I can I need to do a full disassembly with a step by step reassembly.

That's a good point about the accelerometer, I should mention it allows the display to rotate with the throttle so the dial can be at the top or the bottom.

Added to the list 👍

daveclifford, 2023-01-18:
I made this file to ensure I had the correct size and number of screws and the correct assembly order.

One issue you **should highlight** is the need to file the Touchscreen opening for correct size in the Top piece. My display was $40 USD and the most expensive part and could easily be damaged by someone less careful than me..

Please review and see if this may help others. I would be willing to help you - we could chat via WhatsApp.
I am  7 hrs  (Aurora CO) U.S. Mountain Standard  Time before London (GMT) time.

[Screw List and Assembly Order.txt](https://github.com/DCC-EX/EX-T3-WiFi/files/10451332/Screw.List.and.Assembly.Order.txt)

alex-code, 2023-01-18:
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

Thanks for mentioning about the display, I guess the tolerances could vary between 3D printers so some careful trial fitting should be done.

If I can this weekend I'll disassemble then re-assemble getting more pictures along the way.

daveclifford, 2023-01-18:
I'm guessing that the audience for this throttle is wide - with varying degrees of  experience. I can follow your photos ( great job, by the way) and  .md files. I think the area that  needs more explanation is the setup for VSC and PIO to complie and upload the code.  This is NOT simple to understand and use. I know you warned the audience, BUT there are some with little code development experiece that only want to upload and use. Perhaps a compiled code file and easy upload procedure  could facilitate the builder.  The skills needed to build this WiFi Throttle are:
soldering expertease, assembly expertease with very small 2mm screws needing magnification, understanding step building, installing and using VSC and PIO (I think this may be the biggest challenge), and understanding the use of the throttle with the DCC-EX Arduino and (Motor and WiFi) Shields.
I have the skills to build, assemble and use the WiFi Throttle - but I worked for IBM for 40 years as a Software Developer and Team Lead and have tinkered with many software and hardware systems.

I think a list of tools needed to build the WiFi throttle may be helpful.

I am retired and have the time to give you to improve this project.
Unfortunly, we may never meet in person.

Dave

alex-code, 2023-01-21:
Made a start on updating the docs with new pictures and numbered steps.

> I'm guessing that the audience for this throttle is wide - with varying degrees of experience. I can follow your photos ( great job, by the way) and .md files. I think the area that needs more explanation is the setup for VSC and PIO to complie and upload the code. This is NOT simple to understand and use. I know you warned the audience, BUT there are some with little code development experiece that only want to upload and use. Perhaps a compiled code file and easy upload procedure could facilitate the builder.

I had thought about a compiled build but that would require some changes.
With a compiled build I'd have to move the local WiFi generation code to the throttles first turn on, currently it's done with `Python` on the build step in PIO.
I'm not sure if a compiled build would be much easier as you'll still need software to upload.

I can add some extra instructions on using VSCode, PIO and downloading the code.

daveclifford, 2023-01-25:
My guess is that some (like I did) will stumble into this through the DCC-EX Command Station which uses the Arduino IDE - so couldn't that IDE be used to push the compiled build to the FireBeetle2?

I understand your use of Python to build "configuration" code. I just think you'd have a wider group building/using the WiFi Throttle if they didn't have to install/learn/manage two new tools (VSC and PIO).

Why don't you use the Discussion/Poll feature to see if there is interest in a compiled build? Maybe I'm dreaming and your current audience is so small NOT for you to warrant the code changes to go to a compiled build.

I am committed to seeing this through .....  Using Linux as the development platform caused security issues with using a USB port with the PIO app, so I bought a small MiniPC (Beelink Mini PC, Mini S Intel 11th Gen 4-Cores N5095, Mini Desktop Computer with W11Pro) just to build/install the code. I am going to set it up by 27th January. --- stay tuned!!

I saw your videos and was intrigued.............

(I sometimes write this (as I am now at 2125 MST US) while sipping a red beverage - it may not be coempletely coherent).

[There appears no automagic spell checker - RATS!]

Kind Regards,

Dave

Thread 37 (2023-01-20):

Docs - Names of files are one word but titles in files are more descriptive

daveclifford, 2023-01-20:
**Is your feature request related to a problem? Please describe.**
I have to read the file to understand what it does - I think the file name should describe what the file contents is describing.

**Describe the feature you'd like**

Original File Name  - New file name

Assembly - WiFi_Throttle_Assembly
Code -  Uploading_The_WiFi_Throttle_Code
Locos - Setting_Up_And_Managing_Locos
Menu - WiFI_Throttle_Menu
Decoder Programming  -  Programming_The_Loco_Decoder
Running - Running_Locos
Settings - WiFi_Throttle_Settings
Setup - WiFi_Throttle_Setup

If you are worried about spaces in the file names , use underscores for spaces (as I suggest).

I also strongly feel that you should use the word "WiFi"  in your documentation to emphasize that this is an untethered wireless throttle.

**I am in awe** when I touch the throttle case components; you **did an excellent job** in planning and creating the case components - particularly the frame to hold the FireBeetle2, the accelerometer, the rotary encoder and the switch. **Kudos to you!**

alex-code, 2023-01-21:
Good idea. I guess not every user will be using the `README` to get to the other instructions.

Thanks for the compliments, It took a fair few hours of thinking and playing around before I came up with the design.
I would like to make it slimmer but using off the shelf components I have to be a bit more liberal with space.

daveclifford, 2023-01-22:
I will send you a JPG of a case for another WiFi throttle that leaves a lot to desire - after you see it, you will be very satisfied to know that you did a great job  in making a case that fits well in a small hand (mine) . I'm glad you chose a large TouchScreen (for us older folks) and that probably dictated the case dimensions (width and length).

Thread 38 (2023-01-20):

Exhausting Heat In The Throttle Case, Being Able To See the LEDs, and Pushing the RST button on the FireBeetle2

daveclifford, 2023-01-20:
**Is your feature request related to a problem? Please describe.**
The case encloses electronic components that generate heat and there are no holes/slots for the heat to escape.

**Describe the feature you'd like**

1. Perhaps a small slot on the side opposited the switch and USB-C socket would allow heat to escape.
    FireBeelte2 - ESP32-E - Max Discharge Current: 600mA@3.3V LDO
    FireBeetle2 -  ESP32-E -Max Charge Current: 500mA

3. Is the LED on the FireBeetle 2 used to signal errors in uploading the code2.
If so, maybe there could be a way for a small hole to be drilled, so the user could see the light or maybe the screen could provide a warning  that the reset button wouldd have to be pushed. Maybe the battery could be moved down so a rod couild be poked into a hole in the base to momentarily reset the switch.

**Additional context**
Add any other context or screenshots about the feature request here.

daveclifford, 2023-01-20:
In placing the FireBeetle2 into the frame, I discovered that the two buttons (RST and D4/27) on the FireBeetle2 are obscured by:

1. a post to mount the on/off switch, and,
2. a post to tighten the bottom of the case to the frame.

A solution is to allow a small thin tool to be used to push the RST button and the user would have to file a very little material from the inside of the corner post to allow clearance for the tool to be able to push in the RST button.

I do not know if the RST button would ever be needed to be used, but it wouldn't hurt to make the modification to the frame **before** it was needed. If needed and the frame is unmodified, the user would have to disassemble the FrieBeetle2 from the frame to reset the microprocessor. Painful and risky!

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

alex-code, 2023-01-21:
To be honest I've not tested for heat so can't say whether it'll be an issue.
The only issue with holes on a vertical wall is that they can be tricky to 3D print uniformly.

The one LED that's probably relevant is the charging one as it has some flash sequences.

The `RST` button shouldn't be needed (think it'll only reset the ESP32 too) as the wired in switch effectively does the same thing but will also reset the display.

daveclifford, 2023-01-22:
Today, I started to assemble the components to the throttle frame. In particular, I was able to use 4 M2x6mm self-tapping Cap Head Screws (vs M2x5mm as the assembly steps suggest). The bottom of the frame is sufficiently thick enough to provide clearance where the sharp end of the screw does not show  outside the frame (whew!).

I also think the some small holes could be drilled into the bottom of the case to provide a) ventilation, and b) the ability to see the LEDs. This is not needed now, but could be an enhancement for a later date. There is a thickl web going across the short end of the case that could be drilled and still provide substantial support.

daveclifford, 2023-01-22:
I forgot to mention - you may wish to add a note in  the Assembly.MD that the case components may need to be filed - in particular, the holes for the On/Off Switch and FireBeetle2 USB-C Connector. I noticed that there is some schmutz left from the 3D printing process; the two holes for the On/Off Switch and USB-C Connector and the four holes in the bottom of the case - the recess for the screw heads were not clean.

daveclifford, 2023-02-01:
When I get the WiFi Throttle asssembled, I'll throw a Milliampmeter on the unit and measure the current draw. I'm curious to see how long the 3000 mah battery will last.

daveclifford, 2023-05-20:
i decided to measure the temp and report back to you

daveclifford, 2023-07-28:
Alex,

I think in the next 3-4 days I will insert a digital thermometer in the
case, turn it on and seal the gaps on the side with tape and let it run for
24 hrs, then take a measurement and report to you.

Dave

On Thu, Jul 20, 2023 at 8:07 PM github-actions[bot] <
***@***.***> wrote:

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

Closed 2023-10-05.

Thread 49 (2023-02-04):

Browser based code upload

alex-code, 2023-02-04:
Investigate https://github.com/esphome/esp-web-tools for possible uploading of firmware using a browser.

Notes:
- Would require the throttle WiFi SSID and pass to be generated on the throttle.
- Serial support currently only in Chromium based browsers.

TODO:
- [x] Move throttle AP SSID and password generation to the throttle
- [x] Make python script to build and merge into single binary
- [x] Remove conditional defines as they're no use with a binary build, `accelerometer` and `mask password`.
- [x] Test python script to build combined binary that can be used by esp-web-tools
- [x] Update docs with instructions for uploading via browser
- [x] Testing of merged binary

daveclifford, 2023-02-04:
Alex,

Great!  Thanks for finding this - *esp-web-tools*.

I believe that the  FireBeetle2 ESP32 chip isn't being set/reset into
bootloader mode, so the load won't work.

*[ref: https://docs.espressif.com/projects/esptool/en/latest/esp32s2/advanced-topics/boot-mode-selection.html
<https://docs.espressif.com/projects/esptool/en/latest/esp32s2/advanced-topics/boot-mode-selection.html>]*

"On many development boards with built-in USB/Serial, esptool.py can
automatically reset the board into bootloader mode. For other
configurations or custom hardware, you will need to check the orientation
of some “strapping pins” to get the correct boot mode:"

I'd prefer to use *esptools.py* as a PlatformIO pre-action prior to
uploading the build.  [The PlatformIO Build System has a rich API that
allows one to attach different pre-/post actions (hooks),,,,,] to use, *but
I haven' seen an example I understand and modify that I could use.*

I'll take a look at the code to see if I can glean some info.

I am at the point where all WiFi throttle components are soldered
(connectors) and attached to the frame. Now the fun part - wiring the
throttle components.
As you suggested, I got some small brass tubing to act as ferrules.

I am also building a DCC-EX Arduino w/MotorShield and WiFi boards, to
provide the power and signal.

I  like working with my hands and get immense satisfaction from building
with parts........

Thanks again,

Dave

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

daveclifford, 2023-02-11:
**"I'm looking into browser based uploading so you'd only need a Chromium based browser.
Will avoid the need to install IDE's and build the code yourself"**

I believe that you will become more famous than you are now.....

I have been developing software since 1970 and I don't think anyone who hasn't used an IDE would be able to go through the steps to successfully:

a) install two software tools, and
b) use PlatformIO to build/upload the build to a FireBeetle2.

More know how to use the Arduino IDE than the VSCode/PlatformIO combo.

Very few will help you add function to your code..., but most will l**ove to upload** the current build to their WiFi Throttle that they built themselves (pride of build and ownership).

**I whole-hardily applaud your interest in providing a binary build file that will be uploaded by a Chromium browser.**

Dave

alex-code, 2023-02-11:
Adafruit have a site where you can upload the binary to flash, I'm just working on a python script to produce a merged build.

https://adafruit.github.io/Adafruit_WebSerial_ESPTool/

daveclifford, 2023-02-11:
I dd a little snooping and saw:

the need for chrome://flags/  and enable the "Experimental Web Platform"

My issue was what serial port to enable (there were many)

We can sort that out..........................

I like this tool - much easier to set up and use - but the poor firefox
users c'est dommage.

Dave

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

alex-code, 2024-08-10:
Binary release now available.

Closed 2024-08-10.

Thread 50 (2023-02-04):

Upload instructions

giraffe167, 2023-02-04:
Iam only really a begginer with using esp32's it would be nice if you could make a step by step instructions to even a video showing how to uploading the code to the esp!

alex-code, 2023-02-08:
I'm not the best at explaining/instructions.
There's a quick start guide here, https://docs.platformio.org/en/latest/integration/ide/vscode.html#quick-start

I'm looking into browser based uploading so you'd only need a Chromium based browser.
Will avoid the need to install IDE's and build the code yourself.

daveclifford, 2023-02-11:
**"I'm looking into browser based uploading so you'd only need a Chromium based browser.
Will avoid the need to install IDE's and build the code yourself"**

I believe that you will become more famous than you are now.....

I have been developing software  since 1970 and I don't think anyone who hasn't used an IDE would be able to go through the steps to **successfully**:

a) install two software tools, and
b) use PlatformIO to build/upload the build to a FireBeetle2.

More know how to use the Arduino IDE than  the VSCode/PlatformIO combo.

Very few will help you add function to your code..., but most will love to upload the current build to their WiFi Throttle that they built themselves  (pride of build and ownership).

I whole-hardily applaud your interest in providing a binary build file that will be uploaded by a Chromium browser.

Dave

giraffe167, 2023-02-18:
Thank you that worked

Closed 2023-02-18.

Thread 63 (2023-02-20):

No loco functions except forward, reverse and speed.

Budman1758, 2023-02-20:
**Describe the bug**
When in the loco screen all I have is fwd & rev and speed. Seems like there should be more "stuff" Is this normal? The fwd ,rev  and speed functions work as they should as far as I can tell. Followed the code upload directions to the letter. (pretty sure anyway)
See attached picture.

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

**Screenshots or debug output**
If applicable, add screenshots or debug output to help explain your problem.

alex-code, 2023-02-20:
Can you tell me what version your CS is?
You'll need to be on the latest ideally as it has new functionality the throttle requires.

Budman1758, 2023-02-20:
I used the Windows installer so I assume it is the latest release version.

alex-code, 2023-02-21:
Do you have a MicroSD card in the throttle with the contents of the sd folder copied?
https://github.com/DCC-EX/EX-T3-WiFi/blob/master/docs/assembly.md#before-starting-assembly

Budman1758, 2023-02-21:
OK. That helps. Don't have any idea how I missed that part.... Musta had a senior moment there...lol. Now I have all the buttons on the loco screen.

Are the icons only assigned to function buttons when customized individually? No "default" icon setup?

alex-code, 2023-02-21:
I didn't include icons with the default function buttons as they may vary between different decoders.

You can create a reusable function set if you've got the same decoders so you don't have to create one with each loco.

Budman1758, 2023-02-21:
Got a good source for appropriate icons? Lots of .svg and .png stuff but not .bmp.

alex-code, 2023-02-21:
I got some icons from here https://www.pngrepo.com then just resized (30x30) and converted to 24bit bmp.
This is a good free image editor program https://www.getpaint.net

Closed 2023-02-22.

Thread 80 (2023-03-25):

Setup instructions

Alan-Lomax, 2023-03-25:
In the setup.md instructions at the bottom it indicates

> If your CS is connected to your local WiFi
> The server and port are dccex and 2560 by default, you'll only need to change these if you changed them on your Command Station

This was not my experience. I needed to replace the server name with the ip address of my CS on my local network.

alex-code, 2023-03-25:
Did you set a static IP with your CS when setting it up?
Could you try a `ping dccex` to see if it's discoverable on your network via the hostname.

Alan-Lomax, 2023-03-25:
Not exactly a static IP address - I set up an IP reservation (which amounts to the same thing). The same MAC address gets the same IP address (via DHCP) every time. Similar to a static IP address but far easier to maintain across a network.

Alan-Lomax, 2023-03-25:
I will try the ping test and report back. (how would that work with more than 1 CS ? )

Alan-Lomax, 2023-03-25:
OK .. as expected pinging the IP address **does work.** but pinging the server name "dccex" **does not**.
It is not clear to me how it could ever work unless a manual entry was added to the hosts file.  (thus manually mapping dccex to a specific  IP address).

alex-code, 2023-03-26:
A bit of googling does mention a possible bug with the ESP8266 firmware and certain routers where it doesn't use the hostname the device provided.

For curiousity would you be able to try without the reservation to see if your router uses the hostname?

Alan-Lomax, 2023-03-27:
`For curiousity would you be able to try without the reservation to see if your router uses the hostname?`

**Done.**
Bottom line - no change

**In detail**

1) Checked my router - "Attached Devices" - CS shows up as ESP_E68F75 and has the reserved address 192.168.27.3
2) From a workstation on that network - and before changing anything - ping by IP works, ping to dccex does not.  ping to ESP_E68F75 does not.
3) On router removed DHCP reservation
4) In arduino IDE modified config.h for ControlStation (DCCEX+Wifi) and enabled a fixed IP address of 192.168.27.3
5) Recompiled and reloaded
6) From Workstation
       ping by IP works, ping to dccex does not.  ping to ESP_E68F75 also does not.
7) Checked my router again - "Attached Devices" - CS shows up as ESP_E68F75 - this info must have come from CS
8) Reverted config.h for DHCP
9) Recompiled and reloaded
10) Redid ping checks - everything as it was.

At no point was there even a sniff of something called dccex ... all the pings reported 'unable to resolve'

As I mentioned before it is not obvious to me how this would work since most home networks do not have DNS server (Which is normally a domain controller) On your home router you enter the IP address of what you want to be your dns server and it is usually provided by your ISP. An individual (Windows or Linux) machine has a DNS resolver cache but that is not the same thing.
Our two IoT devices (Throttle and CS) don't have this capacity and neither does the router. My windows machine off on the side of the IoT devices has a cache (from previous dns lookups) but would not be aware of dccex.  I know I could 'make it work' by adding a manual entry in my local hosts file (essentially a dns override)

Closed 2023-06-02.

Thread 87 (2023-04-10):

Throttle will not reconnect after turning off then back on.

Budman1758, 2023-04-10:
**Describe the bug**

I don't know if this is a DCC-EX "thing" or a problem with the throttle itself. When I turn on the DCC-EX power supply and then turn one of my throttles on everything works as it should. I can turn the main and program tracks on and off and all other functions work fine. I then turn off the throttle and set it aside for a while leaving DCC-EX on. When I come back and turn the throttle back on it does not connect to the power supply. The icon showing connection to the PS shows connected but no functions work. After a short time the connection changes to showing disconnected.

BOTH of the throttles I currently have working show this behavior. Only way to get throttles to reconnect to the power supply is to power cycle it. As stated, this may actually be a DCC-EX bug. Not sure.....

**To Reproduce**
Steps to reproduce the behavior:
1. Turn DCC-EX on.
2. Turn on the throttle and it connects and functions. Turn either main or program tracks on.  (or both)
3. Turn throttle off leaving DCC-EX in track on state.
4. Come back after a bit, turn throttle back on.
5. Throttle does not connect to or control DCC-EX.

**Expected behavior**
Throttle should connect and function.

This is repeatable and constant.

**Additional info**
 - Component: Throttles built as per this website instructions. DCC-EX built as per the instructions there. Recommended Wi-Fi shield and latest version of the DCC-EX software.

alex-code, 2023-04-10:
Could you clarify what you mean by power supply? Is this your Command Station?

Is your CS connected to your home WiFi in station mode or is your CS in Access Point mode?

Budman1758, 2023-04-10:
DCC-EX command station.
Connected to home WiFi

alex-code, 2023-04-10:
How long do you have the throttle off for?
Doing a quick test on my setup the throttle re-connects (only off for about 10 seconds).

Budman1758, 2023-04-10:
> How long do you have the throttle off for? Doing a quick test on my setup the throttle re-connects (only off for about 10 seconds).

If I reconnect that soon it will sometimes work but usually not. But it never keeps working. It may work to turn off or on (track power) once but not anymore after that.

 If you wait over a minute it does not connect at all.

Ash-4, 2023-04-10:
Do you have this problem when using Engine Driver?
Has the DCC-EX WiFi ESP8266 been flashed to version 1.7.4 ?
Is the Mega powered using 7-9 volts to the barrel connector?
Attach the startup logs and diags from the Arduino serial monitor.
For additional diags, use the commands
 <D WIFI 1>  and/or  <D WIT 1>

Budman1758, 2023-04-10:
> Do you have this problem when using Engine Driver?

Yes. Logs on engine driver is showing "connection refused"

>Has the DCC-EX WiFi ESP8266 been flashed to version 1.7.4 ?

Almost sure now this is a DCC-EX command station issue

daveclifford, 2023-04-11:
"Has the DCC-EX WiFi ESP8266 been flashed to version 1.7.4?"
How do I know what version I'm using ??

Dave

Ash-4, 2023-04-11:
Look for a few lines in the DCC-EX startup log.  This is what I see.
15:45:33.238 -> <* Wifi Check: [\r\nOK\r\n\0] *>
15:45:33.238 -> AT+GMR
15:45:33.238 -> AT version:1.7.4.0(May 11 2020 19:13:04)
15:45:33.238 -> SDK version:3.0.4(9532ceb)
15:45:33.238 -> compile time:May 27 2020 10:12:17
15:45:33.238 -> Bin version(Wroom 02):1.7.4
15:45:33.238 -> OK
15:45:33.238 -> <* Found in 17ms *>

Some of the WiFi shields can work with a different version, but when folks have problems with wifi, the first check is the version and the next check is for adequate power.  Without wifi, the usb connection should provide adequate power.  With wifi, there is some question.  I noticed a significant improvement in performance when Mega was powered with 9V to the barrel connector.  Greater than 7V is good.  12V will cause excess heat.  WiFi power requirements may be greater than expected, and several points of potential weakness with USB powered from PC USB port.

You may want to continue the discussion on the discord server; there have been some recent discussion on how to flash the wifi shield.
https://discord.com/invite/PuPnNMp8Qf

Ash-4, 2023-04-11:
Found a recent guide.
https://gist.github.com/nathankellenicki/7008540322c617869cec17226cff579d

There are other wiring options if you do not have the USB/TTL adapter.

daveclifford, 2023-04-11:
Thanks- I'll check out the stream for the version
Dave

alex-code, 2023-04-12:
Good to hear that fixed it.
I'm using a Mega+WiFi combo board and not experienced your issue with that.

Unfortunately the CS doesn't have a way for the throttle to get the power states without a little bit of work.
You need to include a file I've made when compiling and uploading your CS.
https://github.com/DCC-EX/EX-T3-WiFi/blob/master/docs/code.md#command-station

Budman1758, 2023-04-12:
> You need to include a file I've made when compiling and uploading your CS.

Well, that was easy.....  :)

Works like a champ.

Closed 2023-04-12.

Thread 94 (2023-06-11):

3d print possible issue

Wreckingball7, 2023-06-11:
JLCPCB reports that when printing the top there is a very narrow section which might not print correctly.
This is at the top narrow end inside of the cover. Not sure how to correct this myself.
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

alex-code, 2023-06-12:
There's not really anything I can change.
The large red area shown above covers a ribbon cable for the display, if it was made thicker the top might not fit or could rub on the ribbon cable.
This section could be removed but would just look less finished.

The case was designed with FDM printers in mind.

Closed 2023-08-20.

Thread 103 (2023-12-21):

EX-T3 Throttle and JMRI WiThrottle compatibility

FDrebin, 2023-12-21:
**Describe the bug**
Exploration of JMRI WiThrottle server support with DCC EX Throttle.

**To Reproduce**
Steps to reproduce the behavior:
N/A

**Expected behavior**
Functionality to use throttle with JMRI WiThrottle server.

**Screenshots or debug output**
If applicable, add screenshots or debug output to help explain your problem.
N/A

**Additional info**
 - Component: All items purchased via Github links
 - Version: N/A

Closed 2024-08-20.

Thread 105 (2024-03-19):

Throttle not sending commands to CS

FECRwy, 2024-03-19:
Hi,
I've recently built one of the T3 throttles. After a couple of early mistakes(not uploading the Filesystem Image and the code), I was able to get my screen displaying the throttle. I wasn't able to connect to the throttle settings by using DCCEX but could when I used the IP address of the throttle on my network. I then setup a couple of locos and a custom function screen. All of this seemed to work correctly. However, when I then tried to enter a loco, by number or name, I get the next screen with no function buttons and no speed or direction information. I have checked a LocoNet viewer and there is no information coming from the T3 throttle. I get information from iPhone and Android throttles but not the T3. My CS sees the T3 and the screen indicates both WiFi and CS connection,

I think it must just be a communication link that I overlooked but I am at a loss. I have checked my wiring and programming several times and not found any errors or mistakes.

Could anyone please offer some suggestions as to what to do next. I can provide more info if you give me some idea of what.

alex-code, 2024-03-19:
Are you on the latest CS code?
There's some broadcast features used by the throttle.

FECRwy, 2024-03-19:
Hi Alex,
Yes, I downloaded the latest code as far as I know. I also used the most recent version of PlatformIO and had to obtain a GIT file in order for the software to load onto the throttle. All appeared okay.

alex-code, 2024-03-19:
Does the track power button work if you try that?
Just trying to see if any commands are sending.

FECRwy, 2024-03-19:
No, I've tried other buttons such as the accessory ones, the only buttons that appear to function are  the ones in the Loco section. and the Settings section.

alex-code, 2024-03-19:
Are both icons at the top showing as connected (WiFi and CS).

FECRwy, 2024-03-19:
Yes

FECRwy, 2024-03-20:
Alex,

I may have misled you a bit. If I press the accessory button I do get another screen asking for me to input the number however I do not see any traffic on the LocoNet viewer. The throttle does not appear to be transmitting any data after pressing the button.

Rob

Rob Leathley
Hampton, New Brunswick
________________________________
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

alex-code, 2024-03-20:
I'm not sure what loconet is so can't say if that's having an effect.

One way to check if the throttle is sending data would be to try the basic CS emulator.
You'll need to install Python but you can then run `cs_emulator.py` (included with all the code).
This will start a local server and show output in the terminal window to help debug.
Just change the CS IP address on the throttle to the one of the computer running the server.

FECRwy, 2024-03-20:
First the good news. I was able to successfully install Python and run the emulator. The screens and buttons work as expected and there is information in the Terminal window that appear to be correct to me. One thing, I did notice that the function buttons didn't come up until I turned the encoder. I will look into this on my system to make sure that I haven't missed this before.

I tried using my CS IP and I get the same, no response. I imagine that there is something I still need to do with my configuration but I don't know where to start looking.

LocoNet is a network buss system for Digitrax devices to communicate between each other. Other companies, such as NCE, have similar but LocoNet is by far a more complete system. Anyway, my CS is made up of a MEGA clone with two IoTT 5amp Power Shields and an IoTT Red Hat with a M5Stack Stick running communication software. IoTT is a brainchild of Hans Tanner and comprises a number of IoT devices that can be hooked up to a model railroad. Hans has both a YouTube Channel and a Tindie store. The Red Hat has an interface for LocoNet and his software can show what is happening on the buss, so all commands controlling the layout and locomotives are shown. He has videos outlining making a DCCEX command station with his devices. I am just following along with some of those ideas. As stated before, the CS works fine with both Android and iPhone devices as wireless throttles.

I hope that helps explain more about my system. I'm open to suggestions as to do what next?

alex-code, 2024-03-20:
Could you confirm the CS version you're using?

I wonder if this might be because I use the native DCC Ex commands and not wiThrottle so the commands aren't forwarded.

FECRwy, 2024-03-20:
BINGO! I believe that you have the answer. The software is WiThrottle compatible but I don't think it is aware of native DCCEX commands. I'll check with Hans to see if there is a solution from his end.

I appreciate your help in solving my problem. I apologize for missing the obvious. You have a nice throttle here. One day I hope to be able to interface it to my layout.

alex-code, 2024-03-20:
Having done this throttle I've found the world of DCC is far more varied than I ever thought.
I've only ever used a Mega with WiFi shield.

Hopefully it'll be easy to support native commands in IoTT Red Hat.

FECRwy, 2024-03-20:
Thanks for all of your help. I'll figure something out now that I know where I made my mistake.

FECRwy, 2024-03-22:
Hi Alex,
Well it seems that the problem is not so easily dismissed.
I have written Hans and he confirms that the WiThrottle server is both WiThrottle and native DCC-EX compatible. I checked this out by running both my iPhone with WiThrottle app and an Android table running Engine Drive in DCC-EX mode. Both worked with the layout no problem.
I then tried reprogramming the FireBeetle. I got no error messages. I reset the T3 WiFi settings and the throttle does indicate that it has successfully connected to both the network and the CS server. I still cannot get it to control an engine.

Using the CS emulator, it appears to work fine. Here is a copy of the dialogue:
C:\EX-T3-WiFi\EX-T3-WiFi-master\cs_emulator.py:55: SyntaxWarning: invalid escape sequence '\d'
  r = re.search("<t (?P<l>\d+) (?P<s>\d+) (?P<d>\d+)>", cmd)
Socket successfully created
socket binded to 2560
socket is listening
Got connection from ('192.168.2.84', 63381)
<< <U p>
<< <t 3000>
<< <t 3000 126 255>
>> <l 3000 0 32767 0>

<< <t 3000 1 0>
>> <l 3000 0 2 0>

<< <1>
<< <0>

Any suggestions as to what I should look at next?

FECRwy, 2024-03-22:
Don't know why the strikeout font above. It is not that way in the dialogue.

alex-code, 2024-03-24:
I can't find much documentation on IoTT or code so unable to check myself.

You could try using telnet to connect to IoTT to send some native DCC Ex commands to see if they get through.

FECRwy, 2024-03-24:
Here's a link to Hans' IoTT GitHub page: https://github.com/tanner87661/IoTTStick/tree/master
You should be able to find what you are looking for as he uses Open-Source.
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
alex-code, 2024-03-27:
Are you able to connect your IoTT to a computer at the same time as it being on the board?

Looking at the code it has serial output which may help debug and see where it gets too.
There's a serial monitor built in to the Arduino IDE.

FECRwy, 2024-03-27:
This is some feedback I got from Hans. Perhaps this can narrow down our problem source.

The WiThrottle server of the IoTT Stick does support the DCC-EX mode. In fact, it automatically detects it and switches automatically. It can even serve some phones using WiThrottle protocol and  others using DCC-EX. You can try that out with EngineDriver.

By default, it is set to Withrottle commands. To switch the connection over to DCC-EX, it requires the init string as sent by the ED app. If I remember right it is a string containing “DCC-EX” and a software version. Check the ED protocol to see what exactly is send right after connecting in DCC EX mode. Your throttle needs to do the same and the Stick should switch to DCC EX mode for that connection.

Please give it a try and let me know.

alex-code, 2024-03-28:
I've not got an M5 stick or any of the IoTT modules so can't confirm but think I know why it's not working after looking at the IoTT code.

It looks like IoTT won't process a command until it sees a new line character `\n`.

You can try this on the power command.
If you add `_csClient.write("\n");` after line `#77` in `src/DCCExCS.cpp` then compile and upload.

If that does work you can add that new line after each occurrence of `_csClient.write(...);` until I can update (working on other changes).

FECRwy, 2024-03-28:
Well success, sort of. I tried adding the single line and recompiling the code. I got nothing. I then reedited the code by adding the line in front of all the occurrences and recompiled. This time it sort of worked but was very slow to get the CS to respond. Might this be a timing issue? In addition, I was only able to get the Power Switch to work. Trying to control an engine did nothing.

What I found was that it took several presses of the Power buttons to get any response. This did not seem to me to be a question of double tapping a button but rather a lag in the sending and receipt of a command. I also found that the Power buttons did not react as I expected. Pressing ALL OFF or ALL ON didn't turn the power to Main or Prog off or on immediately and required me to press it several times. As I said, it seems like a timing issue.

alex-code, 2024-03-28:
You could try changing lines `#75-#76` to this.
```cpp
char buf[10];
sprintf(buf, "<%d%s>\n", state ? 1 : 0, cmd);
```
So it's sent as one.

There's no delays in the throttle, if a button is pressed it's cmd is sent.

FECRwy, 2024-03-28:
That works fine on the Power Buttons. Does exactly as expected with no wait.

No response for the Loco buttons but I suspect you are just trying to use the Power buttons to try to fix this for now.

alex-code, 2024-03-29:
Maybe IoTT doesn't buffer cmds so it has to all be in one send.

Will need to increase the `buf` size by 1 and add a `\n` to each function between `>"`, e.g. `>\n"`

```cpp
void DCCExCS::acquireLoco(uint16_t address) {
  char buf[12];
  sprintf(buf, "<t %d>\n", address);
  _csClient.write(buf);
}

void DCCExCS::releaseLoco(uint16_t address) {
  char buf[12];
  sprintf(buf, "<- %d>\n", address);
  _csClient.write(buf);
}

void DCCExCS::setLocoThrottle(uint16_t address, int8_t speed, uint8_t direction) {
  char buf[20];
  sprintf(buf, "<t %d %d %d>\n", address, speed, direction);
  _csClient.write(buf);
}

void DCCExCS::setLocoFn(uint16_t address, uint8_t fn, bool state) {
  char buf[18];
  sprintf(buf, "<F %d %d %d>\n", address, fn, state);
  _csClient.write(buf);
}
```

FECRwy, 2024-03-29:
Yes, that works. I can acquire a Loco and set the speed and direction. The Function buttons work too.

I tried the Emergency Stop and it didn't work so I added  "\n" in  _csClient.write("<!>\n"); That seemed to do the trick. Now, what other commands should I edit so that this can be finally solved?

alex-code, 2024-03-29:
For the others if they have `buf` it'll need increasing by 1 then adding `\n`

So
```cpp
char buf[11];
sprintf(buf, "<W %d>", address);
 _csClient.write(buf);
```
becomes
```cpp
char buf[12];
sprintf(buf, "<W %d>\n", address);
 _csClient.write(buf);
```

For `getLocoAddress()` it'll be   `_csClient.write("<R>\n");`

FECRwy, 2024-03-29:
Thank you for you work.  I made those changes and it seems to work as expected. I do some more running and tests over the weekend. I'll also inform Hans as he was interested as well.

alex-code, 2024-03-29:
Thanks for helping test on this too.
I'll add these changes so it'll be included in newer versions.

Closed 2024-03-29.

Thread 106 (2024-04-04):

Random communication problems with EX-CommandStation ?

Rotziboisseur, 2024-04-04:
When I use the throttle,  I randomly encounter speed adjustment issues.
When I want to slow down, the display of the notches behaves erratically and increases the speed instead of reducing it. For example, if I am on speed step 30 and want to reduce the speed to step 26 or 20, the display of the speed step indeed decreases but then, a fraction of a second later, it increases by the value I wanted to decrease and accelerates the locomotive. I have checked the quality of the encoder connections, and there is nothing to report on that front. When I use the JMRI throttle or WiThrottle on my phone (also via a wifi connection), I do not have this problem.
Could this be a software issue? If so, how can I assist in resolving it by producing logs?
Or could the encoder be defective (I do not have a spare part to test)?

Hardware used:
DFRobot EC11 Rotary Encoder SEN0235
DFRobot FireBeetle 2 ESP32-E DFR0654-F

Command station V5.0.7-Prod

Otherwise, a huge thank you for this amazing project of great quality, which deserves to be better known!

alex-code, 2024-04-04:
There is a potential issue I'm trying to diagnose and fix.
I've read that there can be false triggers in certain scenarios on the ESP32 so the throttle thinks you're turning the dial clockwise.

Could you try adding this `WiFi.setSleep(false);` to `src/main.cpp` between lines `#337` and `#338` then compile and upload and see if that helps.

Rotziboisseur, 2024-04-05:
I made the code modification, recompiled it, and uploaded it to the ESP32, but I do not see any change; the problem remains.

Rotziboisseur, 2024-04-25:
I've also made this modification, but unfortunately it doesn't change anything.
Wouldn't that be an interrupt management problem? (I don't have the skills to analyze the code, so I don't know if it's multithreaded or not...)

alex-code, 2024-04-25:
There's a bug in the ESP32 which can cause ghost interrupts in certain scenarios (typically on the 2 pins I used).

I'd read some people had success with `WiFi.setSleep(false);`.

Still testing for a fix but it's tricky to make reproducible.

Rotziboisseur, 2024-04-26:
If I change the encoder connection on pins D2 and D3 of the Firebettle and modify lines 33 and 34 of src/main.cpp accordingly, could this help solve the problem?

alex-code, 2024-04-27:
I think D2 and D3 are used by the GDI port for the display.

Managed to get a scope on pins 36(A0) & 39(A1) and I could see noise.
One other possible solution I read about is adding `adc_power_acquire` which after doing that the noise on the pin didn't show so could be a fix.

In `main.cpp` you'll need to add `#include <driver/adc.h>` at the top then just after `void setup() {` add `adc_power_acquire();` and compile and re-upload.

This will be part of the code in the next update.

Rotziboisseur, 2024-04-30:
Unfortunately, these changes have not led to any improvements.

alex-code, 2024-05-06:
I've done a test branch with different encoder code if you can try that.
https://github.com/DCC-EX/EX-T3-WiFi/blob/encoder-test/src/main.cpp
It's all in `main.cpp` so you'll only need to update that file then compile and re-upload.

Rotziboisseur, 2024-05-06:
Thank you very much for your help, the situation has changed very favorably 👍
There are now no more erratic variations in the speed steps.
After 10 minutes of maneuvers and driving, I still notice a new problem:
Randomly, yet very frequently, the encoder stops responding for 2 to 4 seconds. Even when applying 5 or 10 pulses on the encoder, during this time nothing happens on the control. When the control starts responding to the encoder pulses again, there is no sudden change in the speed steps, so it seems that the encoder pulses are not accounted for at all during this period of time. I can make a short video if it can help understand the problem

alex-code, 2024-05-07:
I might need to rethink the way it works but there can be a delay if the CS is busy.

When you rotate the encoder the throttle sends a command to the CS and won't send another command until it receives a response from the CS which can cause a delay while waiting.
I did it like this for multi throttle support.

What board have you used for your CS?

Rotziboisseur, 2024-05-07:
I use a Mega2560 + WiFi unbranded CS with an EX-MotorShield8874

Rotziboisseur, 2024-05-28:
To ensure that the issue is not coming from the unbranded Mega + Wifi board, I ordered an official Mega board as well as an "official" EX-WiFiShield-8266.

My configuration is now: Arduino Mega 2560 + EX-MotorShield8874 + EX-WiFiShield-8266.
The problem persists with this configuration.

I also had the opportunity to invite a friend who came to my layout with his TCS UWT-100 controller. When the EX-T3-WiFi controller is on and connected to the same locomotive address as the TCS UWT-100, the EX-T3-WiFi controller disrupts the operation of the TCS. Once the EX-T3-WiFi controller is turned off or with another locomotive address selected, the TCS controller works perfectly well with my hardware configuration.

alex-code, 2024-05-29:
Is this the slowness issue?
Not sure how to speed this one up yet without affecting multi throttle support.

Would you be able to create a new issue about the TCS throttle so it's easier to discuss.

Closed 2024-08-20.

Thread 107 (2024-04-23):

Throttle UI button glitch

indexsites, 2024-04-23:
Using a 32 function loco decoder, button icon for F30 turns from pressed to idle state when some other function buttons are pressed or the throttle speed/direction is changed

Steps to reproduce the behavior:
1. Create a button for a function > F28 (note, auto increment/decrement widget stops at 28 but value can be overwritten manually)
2. Control loco and press button for F30
3. Function F30 activates on loco and icon changes from idle to pressed state as expected
4. Change speed/direction or press another sound-related function button and the icon for F30 reverts to idle although the F30 function still runs (in my case F30 mutes the sound)
5. Display is now out of sync with loco state - display shows function is idle (off) but on loco function is still operating.
7. Pressing the F30 button again sets the icon to the pressed state but as soon as the throttle is touched or other sound-related function are used the F30 button icon reverts to idle state again.

Expected behaviour:
The button icon for F30 always remains in pressed state until button for F30 is pressed again and is unaffected by throttle changes or selection/deselection of other sound related functions.

(Note, I haven't tested this with other functions > F28 but I would imagine the same behaviour results.)

Attached annotated
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
screenshots show button icon for F30 (4th button on the 4th row) changes from pressed state to idle state after increasing speed of loco

Additional info:
 - Components all standard: DFRobot FireBeetle 2 - DFR0654-F, DFRobot Fermion: 3.5” 480x320 TFT LCD Capacitive Touchscreen - DFR0669, DFRobot Fermion: EC11 Rotary Encoder - SEN0235 (not using an accelerometer)
 - Version: 4.1.3

alex-code, 2024-04-24:
The throttle doesn't keep track of function states itself and relies on the broadcast from the CS which only tracks fns 0-28 so there's not much I can do.

The CS code is done so it'll work on an Uno which I don't know if it has enough memory to track up to 64 fns per loco.

Are you able to remap F30 to a Fn between 0-28?

indexsites, 2024-04-25:
Thank you for the quick response.  Remapping the function is a good workaround, thank you - I will do that.

In the meantime thank you for all the time and effort you put into this project - I'm really pleased with my throttle and apart from a few minor problems (of my own making) the build was very straightforward.

I'm especially appreciating the ability to configure the UI to my needs - uploading and arranging the button icons is fantastic.

alex-code, 2024-04-25:
Thanks for the positive feedback, glad it's all working for you 👍

Closed 2024-04-25.

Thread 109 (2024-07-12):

Project change for ESP32S3 - WROOM1-N16R8

JozefKc, 2024-07-12:
I would like to ask you, if possible.
I have a **LILYGO T7-S3** what is an _ESP32-S3-WROOM-1-N16R8_ =16M Flash a and 8MB PRAM. I would like to use this processor and I do not have enough experience to change this project. I think it will be useful for many users too.
Best regards.
Joe

alex-code, 2024-07-13:
Extra boards isn't something I can support due to the multi component nature of the project and the 3D parts will only fit the components I've used.

To make development and construction simpler it's easier to use a standard set of components.

Closed 2024-09-19.

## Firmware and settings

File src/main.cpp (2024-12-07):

#include <Arduino.h>
#include <SPIFFS.h>
#include <SD.h>
#include <SPI.h>
#include <TFT_eSPI.h>
#include <GT911.h>
#include <DFRobot_LIS2DW12.h>
#undef ERR_OK // Needed as the DFRobot_LIS2DW12.h header has an unused define that conflicts
#include <WiFi.h>
#include <AsyncTCP.h>
#include <Settings.h>
#include <DCCExCS.h>
#include <Locos.h>
#include <UI.h>
#include <UIHeader.h>
#include <Children/Keypad.h>
#include <Children/MessageBox.h>
#include <Children/Pin.h>
#include <SDCardUI.h>
#include <MenuUI.h>
#include <WiFiUI.h>
#include <SettingsUI.h>
#include <AboutUI.h>
#include <ProgramUI.h>
#include <LocoUI.h>
#include <LocoByNameUI.h>

const uint32_t POWER_CHECK = 60000 * 2; // 2 Minutes
const uint8_t BATTERY_PIN = A2;
const uint8_t GESTURE_DISTANCE = 15;
const uint16_t CONNECTION_ALIVE_DELAY = 5000;

const uint8_t ENCODER_BTN = A3;
const uint8_t ENCODER_B = A1;
const uint8_t ENCODER_A = A0;

TFT_eSPI tft;
GT911 ts;
struct {
  bool enabled = false;
  DFRobot_IIS2DLPC_I2C inst;
  DFRobot_LIS2DW12::eOrient_t last = DFRobot_LIS2DW12::eOrient_t::eYDown;
} acce;

volatile uint8_t encoderLastEncoded = 0;
volatile int8_t encoderCurrentValue = 0;
uint32_t encoderPressMillis = 0;
UI::Encoder::ButtonState encoderBtnState = UI::Encoder::ButtonState::IDLE;
uint8_t encoderCurrentPinState, encoderLastPinState;

AsyncClient csClient;
uint8_t csBuffer[1024];
uint16_t csBufferLen = 0;
DCCExCS dccExCS(csClient);
DCCExCS::Power power;
Locos locos;

std::unique_ptr<UIHeader> uiHeader;
std::unique_ptr<UI> activeUI;
std::function<std::unique_ptr<UI>()> setUI;
bool isMenu;

void setMenuUI();
void setLocoUI();

void setPinUI(uint32_t pin, const Events::EventCallback&& onValid) {
  if (!pin) {
    onValid(nullptr);
  } else {
    setUI = [pin, onValid] {
      auto ui = std::make_unique<Pin>(pin);
      ui->addEventListener(Pin::Event::VALID, std::move(onValid));
      ui->addEventListener(Pin::Event::CANCEL, [](void*) {
        setMenuUI();
      });
      return ui;
    };
  }
}

void setLocoKeypadUI(const Events::EventCallback&& onCancel) {
  setUI = [onCancel] {
    auto ui = std::make_unique<Keypad>("Loco Address", 10293, 0);
    ui->addEventListener(Keypad::Event::ENTER, [](void* parameter) {
      locos.add(*static_cast<uint16_t*>(parameter));
      setLocoUI();
    });
    ui->addEventListener(Keypad::Event::CANCEL, std::move(onCancel));
    return ui;
  };
}

void setLocoByNameUI(bool group) {
  setUI = [group] {
    auto ui = std::make_unique<LocoByNameUI>(group);
    ui->addEventListener(LocoByNameUI::Event::SELECTED, [](void* parameter) {
      locos.add(*static_cast<uint16_t*>(parameter));
      setLocoUI();
    });
    return ui;
  };
}

void setLocoUI() {
  setUI = [] {
    auto ui = std::make_unique<LocoUI>(dccExCS, locos);
    ui->addEventListener(LocoUI::Event::SWIPE_ACTION, [](void* parameter) {
      using Action = SettingsClass::LocoUI::Swipe::Action;
      switch (const auto action = *static_cast<uint8_t*>(parameter)) {
        case Action::KEYPAD: {
          setLocoKeypadUI([](void*) {
            if (locos == 0) {
              setMenuUI();
            } else {
              setLocoUI();
            }
          });
        } break;
        case Action::NAME:
        case Action::GROUP: {
          bool group = action == Action::GROUP;
          setLocoByNameUI(group);
        } break;
        case Action::RELEASE: {
          dccExCS.releaseLoco(locos.remove());
          // if the action after swipe release is prev/next and there's no active locos then go back to menu
          if ((Settings.LocoUI.Swipe.release == Action::NEXT || Settings.LocoUI.Swipe.release == Action::PREV) && locos == 0) {
            setMenuUI();
          } else {
            (static_cast<LocoUI*>(activeUI.get()))->dispatchEvent(LocoUI::Event::SWIPE_ACTION, &Settings.LocoUI.Swipe.release);
          }
        } break;
        case Action::NEXT: {
          locos.next();
          setLocoUI();
        } break;
        case Action::PREV: {
          locos.prev();
          setLocoUI();
        } break;
      }
    });

    return ui;
  };
}

void setAccessoryKeypadUI(bool state) {
  setUI = [state] {
    auto ui = std::make_unique<Keypad>("Accessory Address", 2044, 1);
    ui->addEventListener(Keypad::Event::ENTER, [state](void* parameter) {
      dccExCS.accessory(*static_cast<uint16_t*>(parameter), state);
      setMenuUI();
    });
    ui->addEventListener(Keypad::Event::CANCEL, [](void*) {
      setMenuUI();
    });
    return ui;
  };
}

void setMenuUI() {
  setUI = [] {
    isMenu = true;
    auto ui = std::make_unique<MenuUI>(dccExCS, power);
    ui->addEventListener(MenuUI::Event::SELECTED, [](void* parameter) {
      switch (const auto button = *static_cast<MenuUI::Button*>(parameter)) {
        case MenuUI::Button::LOCO_LOAD_BY_ADDRESS: {
          setLocoKeypadUI([](void*) {
            setMenuUI();
          });
        } break;
        case MenuUI::Button::LOCO_LOAD_BY_NAME:
        case MenuUI::Button::LOCO_LOAD_BY_GROUP: {
          bool group = button == MenuUI::Button::LOCO_LOAD_BY_GROUP;
          setLocoByNameUI(group);
        } break;
        case MenuUI::Button::LOCO_RELEASE: {
          dccExCS.releaseLoco(locos.remove());
        } break;
        case MenuUI::Button::LOCO_PROGRAM: {
          setUI = [] {
            return std::make_unique<ProgramUI>(dccExCS);
          };
        } break;
        case MenuUI::Button::ACCESSORY_ON:
        case MenuUI::Button::ACCESSORY_OFF: {
          bool state = button == MenuUI::Button::ACCESSORY_ON;
          setAccessoryKeypadUI(state);
        } break;
        case MenuUI::Button::POWER_ON_ALL:
        case MenuUI::Button::POWER_OFF_ALL: {
          bool state = button == MenuUI::Button::POWER_ON_ALL;
          dccExCS.setCSPower(DCCExCS::Power::ALL, state);
        } break;
        case MenuUI::Button::POWER_ON_MAIN:
        case MenuUI::Button::POWER_OFF_MAIN: {
          bool state = button == MenuUI::Button::POWER_ON_MAIN;
          dccExCS.setCSPower(DCCExCS::Power::MAIN, state);
        } break;
        case MenuUI::Button::POWER_ON_PROG:
        case MenuUI::Button::POWER_OFF_PROG: {
          bool state = button == MenuUI::Button::POWER_ON_PROG;
          dccExCS.setCSPower(DCCExCS::Power::PROG, state);
        } break;
        case MenuUI::Button::POWER_JOIN: {
          dccExCS.setCSPower(DCCExCS::Power::JOIN, true);
        } break;
        case MenuUI::Button::WIFI: {
          setPinUI(Settings.pin, [](void*) {
            setUI = [] {
              return std::make_unique<WiFiUI>();
            };
          });
        } break;
        case MenuUI::Button::SETTINGS: {
          setPinUI(Settings.pin, [](void*) {
            setUI = [] {
              return std::make_unique<SettingsUI>();
            };
          });
        } break;
        case MenuUI::Button::ABOUT: {
          setUI = [] {
            return std::make_unique<AboutUI>(dccExCS);
          };
        } break;
      }
    });
    return ui;
  };
}

void IRAM_ATTR updateEncoderValue() {
  uint8_t MSB = digitalRead(ENCODER_A);
  uint8_t LSB = digitalRead(ENCODER_B);

  uint8_t encoded = (MSB << 1) | LSB;
  uint8_t sum  = (encoderLastEncoded << 2) | encoded;

  switch (sum) {
    case 0b1101:
    case 0b0100:
    case 0b0010:
    case 0b1011: {
      encoderCurrentValue++;
    } break;
    case 0b1110:
    case 0b0111:
    case 0b0001:
    case 0b1000:
      encoderCurrentValue--;
  }

  encoderLastEncoded = encoded;
}

// Based off the helpful blog post here, https://savjee.be/2020/02/esp32-keep-wifi-alive-with-freertos-task/
void keepWiFiAlive(void*) {
  for (;;) {
    if (Settings.CS.valid()) { // Valid if we have SSID, Server & Port
      if (WiFi.status() != WL_CONNECTED) {
        WiFi.begin(Settings.CS.SSID().c_str(), Settings.CS.password().c_str());
      }
    }
    vTaskDelay(CONNECTION_ALIVE_DELAY / portTICK_PERIOD_MS);
  }
}

void connectToCS() {
  if (WiFi.status() == WL_CONNECTED) {
    csClient.connect(Settings.CS.server().c_str(), Settings.CS.port());
  }
}

void powerCheck(void*) {
  for (;;) {
    uint32_t total = 0;
    for (uint8_t i = 0; i < 10; i++) {
      total += analogReadMilliVolts(BATTERY_PIN);
      delay(100);
    }

    float voltage = total / 10;
    voltage *= 2;
    voltage /= 1000;

    uiHeader->setPowerStatus(voltage);
    vTaskDelay(POWER_CHECK / portTICK_PERIOD_MS);
  }
}

void setRotation() {
  bool standard = Settings.rotation == SettingsClass::Rotation::STANDARD;
  if (Settings.rotation == SettingsClass::Rotation::ACCELEROMETER) {
    standard = acce.enabled ? acce.last == DFRobot_LIS2DW12::eOrient_t::eYDown : true;
  }

  UI::tft->setRotation(standard ? 2 : 0);
  ts.setRotation(standard ? GT911::Rotate::_180 : GT911::Rotate::_0);

  if (activeUI != nullptr) {
    UI::tft->fillScreen(TFT_BLACK);
    uiHeader->handleRedraw();
    activeUI->handleRedraw();
  }
}

void setup() {
  Serial.begin(115200);

  // Start file systems
  SPIFFS.begin();
  uint8_t tries = 3;
  while (!SD.begin(D7) && tries-- > 0) {
    delay(100);
  }

  // Start the TFT display
  UI::tft = &tft;
  UI::tft->init();
  UI::tft->fillScreen(TFT_BLACK);
  UI::tft->setTextColor(TFT_WHITE, TFT_BLACK);
  UI::tft->loadFont("fonts/FreeSans-18");

  // pinMode(12, OUTPUT);
  // digitalWrite(12, HIGH); // Keep backlight on
  // digitalWrite(12, LOW); // Turn off backlight
  // TODO, screen standby? can it remember buffer

  // Start the touchscreen
  ts.begin();

  // Start the accelerometer
  if (acce.inst.begin()) {
    acce.inst.softReset();
    acce.inst.setRange(DFRobot_LIS2DW12::e2_g);
    acce.inst.setPowerMode(DFRobot_LIS2DW12::eContLowPwrLowNoise1_12bit);
    acce.inst.setDataRate(DFRobot_LIS2DW12::eRate_200hz);
    acce.inst.set6DThreshold(DFRobot_LIS2DW12::eDegrees60);
    acce.inst.setInt1Event(DFRobot_LIS2DW12::e6D);
    delay(25);
    acce.enabled = true;
    acce.last = acce.inst.getOrientation();
  }

  // Setup encoder
  pinMode(ENCODER_BTN, INPUT);
  pinMode(ENCODER_A, INPUT_PULLUP);
  pinMode(ENCODER_B, INPUT_PULLUP);
  attachInterrupt(ENCODER_A, updateEncoderValue, CHANGE);
  attachInterrupt(ENCODER_B, updateEncoderValue, CHANGE);

  // Unable to mount SD card
  if (SD.cardType() == CARD_NONE) {
    UI::tft->setRotation(2);
    ts.setRotation(GT911::Rotate::_180);

    setUI = [] {
      return std::make_unique<SDCardUI>();
    };

    return;
  }

  // Load the settings
  Settings.load();

  // Set initial rotation
  setRotation();

  // Rotation settings change
  Settings.addEventListener(SettingsClass::Event::ROTATION_CHANGE, [](void*) {
    if (acce.enabled) {
      acce.last = acce.inst.getOrientation();
    }
    setRotation();    
  });

  // Setup the WiFi
  WiFi.setHostname(Settings.AP.SSID.c_str());
  WiFi.persistent(false);
  WiFi.mode(WIFI_STA);
  WiFi.setSleep(false);
  
  // WiFi connected
  WiFi.onEvent([](WiFiEvent_t event, WiFiEventInfo_t info) {
    uiHeader->setWiFiStatus(true);
    connectToCS();
  }, ARDUINO_EVENT_WIFI_STA_GOT_IP);
  // WiFi disconnected
  WiFi.onEvent([](WiFiEvent_t event, WiFiEventInfo_t info) {
    uiHeader->setWiFiStatus(false);
  }, ARDUINO_EVENT_WIFI_STA_DISCONNECTED);
  // CS connected
  csClient.onConnect([](void* arg, AsyncClient* client) {
    uiHeader->setCSStatus(true);
    dccExCS.getCSPower(); // Get current power status
  });
  // CS disconnected
  csClient.onDisconnect([](void* arg, AsyncClient* client) {
    uiHeader->setCSStatus(false);
    connectToCS();
  });
  // If the connection to the CS times out then close it so it'll attempt a reconnect
  csClient.onTimeout([](void* arg, AsyncClient* client, uint32_t time) {
    csClient.close();
  });
  // CS data
  csClient.onData([](void* arg, AsyncClient* client, void* data, uint16_t len) {
    for (uint16_t i = 0; i < len; i++) {
      if (static_cast<uint8_t*>(data)[i] == '<') { // Start of cmd
        csBuffer[0] = '\0';
        csBufferLen = 0;
      } else if (static_cast<uint8_t*>(data)[i] == '>') { // End of cmd, pass onto ex cs handler
        csBuffer[csBufferLen] = '\0';
        dccExCS.handleCS(csBuffer, csBufferLen);
      } else {
        // TODO, only add to buffer if we're in a command?
        csBuffer[csBufferLen++] = static_cast<uint8_t*>(data)[i];
      }
    }
  });

  // Aquired loco count change
  locos.addEventListener(Locos::Event::COUNT_CHANGE, [](void* parameter) {
    auto count = *static_cast<uint8_t*>(parameter);
    uiHeader->setLocoCount(count);
  });

  // CS Power event
  dccExCS.addEventListener(DCCExCS::Event::BROADCAST_POWER, [](void* parameter) {
    power = *static_cast<DCCExCS::Power*>(parameter); // Remember current power states
  });

  // If the CS settings change we disconnect so the keep alive task will reconnect using new values
  Settings.addEventListener(SettingsClass::Event::CS_CHANGE, [](void*) {
    WiFi.disconnect();
  });

  xTaskCreatePinnedToCore(powerCheck, "powerCheck", 1024, NULL, 1, NULL, 1);
  xTaskCreatePinnedToCore(keepWiFiAlive, "keepWiFiAlive", 2048, NULL, 1, NULL, 1);

  // Create UI Header
  uiHeader = std::make_unique<UIHeader>();
  uiHeader->addEventListener(UIHeader::Event::MENU, [](void*) {
    if (isMenu) {
      if (locos != 0) { // If we're already on the menu and there's an active loco switch to the loco UI
        setLocoUI();
      }
    } else { // Load the menu UI
      setMenuUI();
    }
  });
  // Start with the menu
  setMenuUI();
}

void loop() {
  if (setUI != nullptr) {
    isMenu = false; // Any new UI resets this
    UI::tft->fillRect(0, 30, 320, 450, TFT_BLACK);
    activeUI.reset();
    activeUI = setUI();
    setUI = nullptr;
  }

  // Encoder press
  encoderCurrentPinState = digitalRead(ENCODER_BTN);
  if (encoderCurrentPinState != encoderLastPinState) {
    if (millis() - encoderPressMillis > 50) { // Debounce
      if (encoderCurrentPinState == LOW && encoderBtnState == UI::Encoder::ButtonState::IDLE) { // Press
        encoderBtnState = UI::Encoder::ButtonState::PRESSED;
      } else if (encoderCurrentPinState == HIGH && encoderBtnState == UI::Encoder::ButtonState::PRESSED) { // Release
        encoderBtnState = UI::Encoder::ButtonState::RELEASED;
      }
    }
    encoderPressMillis = millis();
  }
  encoderLastPinState = encoderCurrentPinState;

  uint8_t touches = ts.touched(GT911_MODE_POLLING);
  if (touches) {
    // Remember the original touch points so we can use later calls to check for swipes
    GTPoint points[touches];
    memcpy(points, ts.getPoints(), touches * sizeof(GTPoint));
    // If menu press
    if (uiHeader == nullptr || !uiHeader->handleTouch(touches, points, [] {
      return ts.touched(GT911_MODE_POLLING);
    })) {
      // Attempt to detect swipe
      UI::Swipe swipe = UI::Swipe::NONE;
      delay(5);
      uint32_t timeout = millis() + 150;
      while (millis() < timeout && ts.touched(GT911_MODE_POLLING)) {
        GTPoint p = ts.getPoint(0);
        if (points[0].y - p.y > GESTURE_DISTANCE) {
          swipe = UI::Swipe::UP;
        } else if (p.y - points[0].y > GESTURE_DISTANCE) {
          swipe = UI::Swipe::DOWN;
        } else if (points[0].x - p.x > GESTURE_DISTANCE) {
          swipe = UI::Swipe::LEFT;
        } else if (p.x - points[0].x > GESTURE_DISTANCE) {
          swipe = UI::Swipe::RIGHT;
        }
        if (swipe != UI::Swipe::NONE) {
          while (ts.touched(GT911_MODE_POLLING)) {
            delay(10);
          }
          break;
        }
      }

      if (swipe == UI::Swipe::NONE) {
        activeUI->handleTouch(touches, points, [] {
          return ts.touched(GT911_MODE_POLLING);
        });
        Serial.println(ESP.getFreeHeap());
      } else {
        activeUI->handleSwipe(swipe);
      }
    }
  } else if (encoderCurrentValue >= 3) {
    encoderCurrentValue = 0;
    activeUI->handleEncoderRotate(UI::Encoder::Rotation::CW);
  } else if (encoderCurrentValue <= -3) {
    encoderCurrentValue = 0;
    activeUI->handleEncoderRotate(UI::Encoder::Rotation::CCW);
  } else if (encoderBtnState == UI::Encoder::ButtonState::PRESSED && millis() - encoderPressMillis > Settings.emergencyStop) { // Encoder pressed and held for set duration
    encoderBtnState = UI::Encoder::ButtonState::IDLE;
    dccExCS.emergencyStopAll(); // Stop all locos
    activeUI->handleEncoderPress(UI::Encoder::ButtonPress::LONG);
  } else if (encoderBtnState == UI::Encoder::ButtonState::RELEASED && millis() - encoderPressMillis < 1000) { // Encoder pressed for less than 1 second
    encoderBtnState = UI::Encoder::ButtonState::IDLE;
    activeUI->handleEncoderPress(UI::Encoder::ButtonPress::SHORT);
  } else if (Settings.rotation == SettingsClass::Rotation::ACCELEROMETER && activeUI != nullptr && acce.enabled) {
    DFRobot_LIS2DW12::eOrient_t orientation = acce.inst.getOrientation();
    if (orientation != acce.last && (orientation == DFRobot_LIS2DW12::eYDown || orientation == DFRobot_LIS2DW12::eYUp)) {
      acce.last = orientation;
      setRotation();
    }
  }

  if (uiHeader != nullptr) {
    uiHeader->handleTasks();
  }

  activeUI->handleTasks();
  activeUI->handleLoop();

  delay(1);
}

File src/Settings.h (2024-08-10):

#ifndef SETTINGS_H
#define SETTINGS_H

#include <Version.h>
#include <Events.h>
#if __has_include(<ThrottleWiFiSettings.h>)
// TODO, deprecate
#include <ThrottleWiFiSettings.h>
#endif
#include <IPAddress.h>
#include <ArduinoJson.h>

class SettingsClass : public Events {
  public:
    struct Event {
      static constexpr uint8_t CS_CHANGE = 0;
      static constexpr uint8_t ROTATION_CHANGE = 1;
    };
    struct Rotation {
      static constexpr uint8_t STANDARD = 0;
      static constexpr uint8_t INVERTED = 1;
      static constexpr uint8_t ACCELEROMETER = 2;
    };

    uint32_t version = 0;
    uint8_t rotation = Rotation::STANDARD;
    uint32_t pin = 0;
    uint16_t emergencyStop = 2000;

    void load();
    void save();
    void init();
    void upgrade(JsonDocument& doc);

    struct AP {
      friend class SettingsClass;

      String SSID;
      String password;

      private:
        void load(const JsonObject& obj);
        void save(const JsonObject& obj); 
    } AP;

    struct CS {
      friend class SettingsClass;
        
      bool valid();

      String SSID() const;
      bool SSID(const String& value);

      String password() const;
      bool password(const String& value);

      String server() const;
      bool server(const String& value);

      uint16_t port() const;
      void port(uint16_t value);
    
      CS() {
        _ssid.reserve(32);
        _password.reserve(63);
      }

      private:
        String _ssid;
        String _password;
        String _server = "dccex";
        uint16_t _port = 2560;

        void load(const JsonObject& obj);
        void save(const JsonObject& obj);
    } CS;

    struct LocoUI {
      friend class SettingsClass;

      struct SpeedStep {
        static constexpr uint8_t STEP_1 = 0;
        static constexpr uint8_t STEP_2 = 1;
        static constexpr uint8_t STEP_4 = 2;
      };

      uint8_t speedStep = SpeedStep::STEP_1;

      struct Swipe {
        friend class SettingsClass::LocoUI;

        struct Action {
          static constexpr uint8_t NONE = 0;
          static constexpr uint8_t KEYPAD = 1;
          static constexpr uint8_t NAME = 2;
          static constexpr uint8_t GROUP = 3;
          static constexpr uint8_t NEXT = 4;
          static constexpr uint8_t PREV = 5;
          static constexpr uint8_t RELEASE = 6;
        };

        uint8_t up = Action::RELEASE;
        uint8_t down = Action::KEYPAD;
        uint8_t left = Action::NEXT;
        uint8_t right = Action::PREV;

        uint8_t release = Action::KEYPAD;

        private:
          void load(const JsonObject& obj);
          void save(const JsonObject& obj);  
      } Swipe;

      private:
        void load(const JsonObject& obj);
        void save(const JsonObject& obj);
    } LocoUI;
};

extern SettingsClass Settings;

#endif

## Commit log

2022-11-23 Added step design files
    [Battery Strap - 2000mah.step, Battery Strap - 3000mah.step, Body.step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]
2022-12-04 Rewrite and new features (#4)
    * New features (Keyboard, MessageBox)
    Updates to `ProgramUI`
    * Refactoring
    UI class reworked to make new UI's simpler to add.
    Simplified some consts so `static_cast` isn't needed.
    * Fixes
    * Docs
    [LocoUI.cpp]
2022-12-04 Missing directory fix git doesn't allow empty directories. The throttle server now creates as needed
    [ThrottleServer.cpp]
2023-01-02 Refactoring, enhancements and fixes. Lots of changes to make future feature updates easier. Fixed some issues.
    [LocoUI.cpp, UIHeader.cpp]
2023-01-06 More changes... Removed need for RTTI Move child UI creation and reset to tasks
    [LocoUI.cpp, main.cpp]
2023-01-12 ArduinoJson version update
2023-01-15 pin protect for WiFi and settings
2023-01-19 More changes... Reorganised files. Updated TFT_eSPI to 2.5.0. Enhanced `Button` to have optional rounded sides (for future idea).
2023-02-08 Throttle AP SSID & Pass gen moved to throttle code. Prep for providing binary builds.
2023-02-18 Arduino IDE fix for `myFilter`
2023-04-23 Encoder response improvement Single throttle response speed improved
